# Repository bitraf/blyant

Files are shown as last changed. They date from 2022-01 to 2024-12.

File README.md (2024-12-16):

# Bitraf's musikalske blyant
Et elektronikk byggesett for å lære seg å lodde, som du også kan ha masse morro med. Settet er laget til [Bitraf's Crowdfunding kampanje i 2021](https://www.spleis.no/project/175973). Om du vil ha et sett nå etter kampanjen, kan du besøke Bitraf i Brenneriveien 9 og kjøpe ditt eget sett i Bitmart.

Byggesettet er basert på Drawdio og alle filene redistribueres her under samme lisens (CC BY-SA 3.0). Bitraf's version was made by [jenschr](https://github.com/jenschr). Based on work by Jay Silver in the Lifelong Kindergarten group at the MIT Media Lab (CC BY-SA 3.0). 

## Instruksjoner
For å bygge settet trenger du en loddebolt, en avbiter-tang og litt loddetinn. Om du ikke har dette kan du stikke innom Bitraf og låne utstyr hos oss. Følg [instruksjonene du finner her](instruksjoner/instruksjoner.md), så kommer du i mål.

### Innhold i settet
* Blyant
* Kobber-tape
* Tegnestift
* 2 strips/buntebånd
* Lilla kretskort
* Høyttaler
* 300k brun motstand (R2)
* 10k liten, oransje motstand (R1)
* 0.1uF oransje kondensator (C2)
* 680pF blå kondensator (C3)
* 100uF polarisert kondensator (C1)
* PN2222 transistor
* PN2907ATF transistor
* TLC551CP chip
* Chip-holder
* 2 Batteri-holdere

## skjematikk
Skjematikk for kretskortet finnes i form av [PDF](BitrafDrawdio_skjematikk.pdf) og komplette [Kicad-filer](kretskort/).

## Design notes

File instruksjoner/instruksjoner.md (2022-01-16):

# Instruksjoner
For å bygge settet trenger du en loddebolt, en avbiter-tang og litt loddetinn. Om du ikke har dette kan du stikke innom Bitraf og låne utstyr hos oss.

Komponentene faller lettere ut hvis du lodder de høye komponentene først. Det er derfor lurt å starte med de laveste komponentene. 

Start med de to motstandene (R1 og R2). Bøy bena ca 90 grader så de passer inn i hullene og skyv motstanden helt ned mot kortet så bena stikker langt ut på baksiden. Snu kortet og bøy litt bena ut.

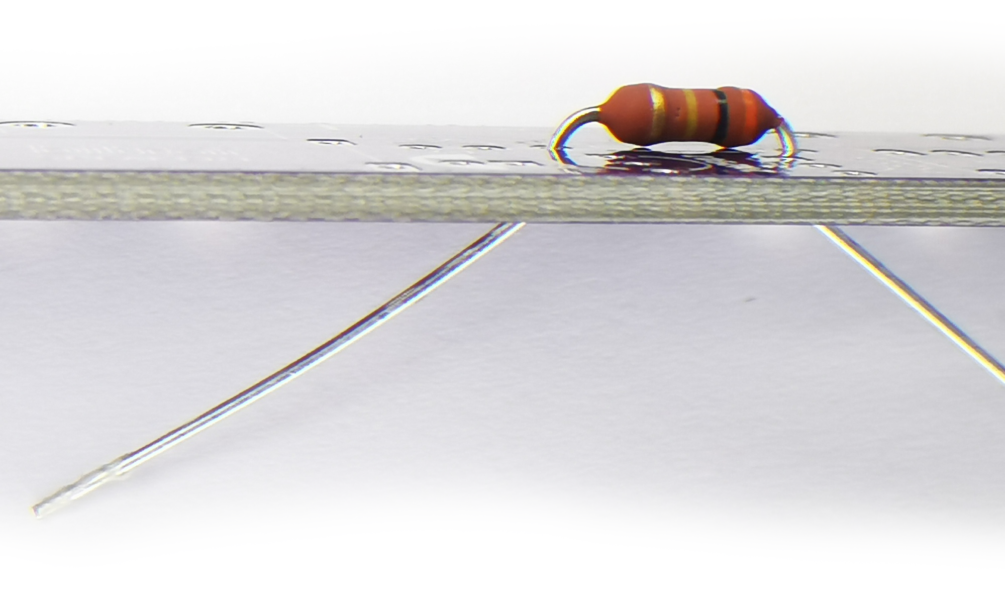
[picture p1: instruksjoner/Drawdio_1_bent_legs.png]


Dette gjør at motstanden holder seg på plass mens du lodder den. Det er lettere å få riktig mengde loddetinn hvis man bruker tynt loddetinn (0.5mm), men du kan bruke det du har tilgjengelig.

Start med å ta bittelitt loddetinn på tuppen av loddebolten - så lite at tuppen blir "våt", men ikke så mye at det danner seg en dråpe. Dette gjør det lett for varmen å krype fra loddebolten og over til det vi skal lodde. Plasser tuppen av loddebolten så den både rører hullet og benet på motstanden vi skal lodde.

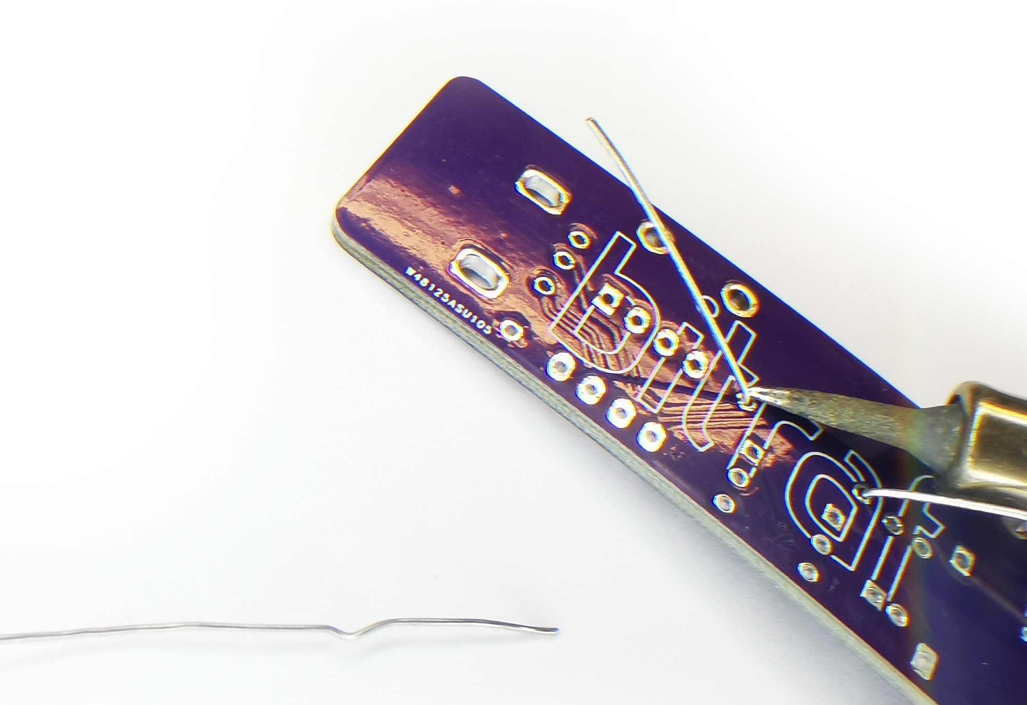
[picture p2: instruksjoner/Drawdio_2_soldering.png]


Målet er at du skal ta på nok loddetinn til å fylle igjen hullet, men ikke så mye at det ser ut som det ligger en dråpe der. Den perfekte mengden loddetinn ser ut som en liten fjelltopp som trekker seg oppover benet på komponenten. Hvis du ikke har så mye loddet før, anbefaler vi å sjekke ut den [flotte guiden](FullSolderComic_EN.pdf) som [Mighty Ohm](https://mightyohm.com/blog/2011/04/soldering-is-easy-comic-book/) har laget. Det er denne vi bruker på loddekurs på Bitraf.

Når begge bena er loddet, klipper du av bena så langt ned mot kortet som du kan med en tang.

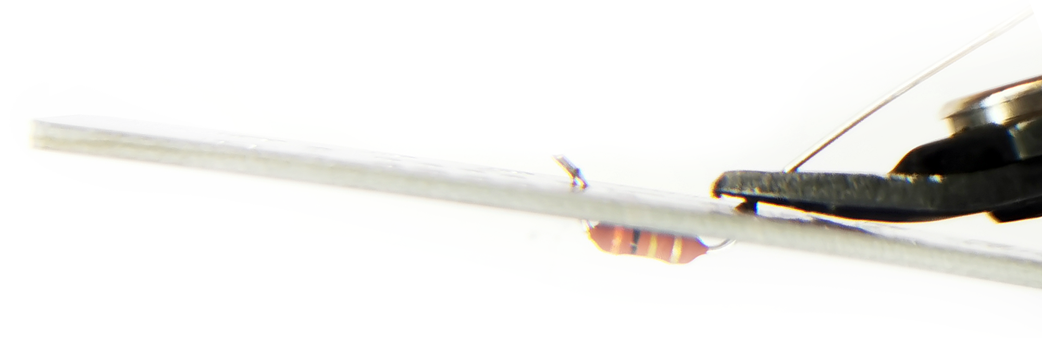
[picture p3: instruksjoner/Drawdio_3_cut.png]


Gjenta prosessen for den andre motstanden. Hvis du sliter med å finne noen av komponentene - let gjerne i nærheten av høyttaleren? Denne er magnetisk, så den har en viss samlende effekt... Vær også litt ekstra forsiktig med den, så ikke høyttaler-membranet blir skadet.

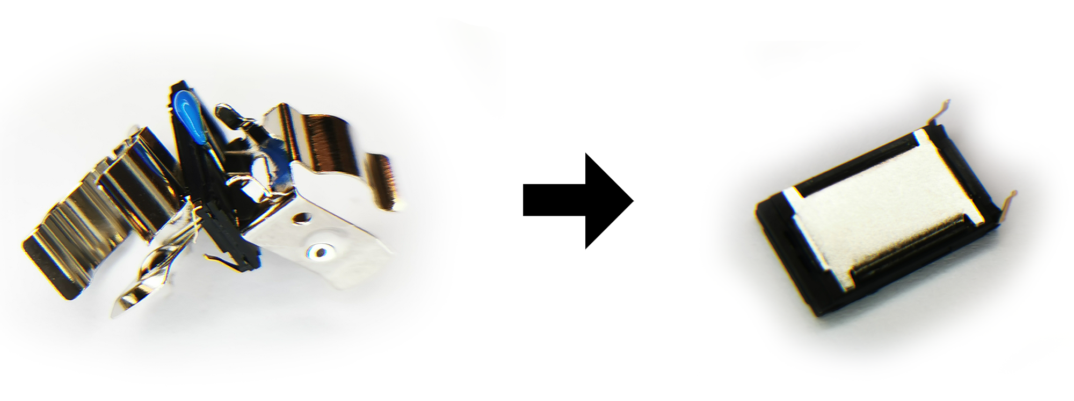
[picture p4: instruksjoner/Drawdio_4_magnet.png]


Lodd deretter de to kondensatorene som er små (C3 først og så C2). Når disse er på plass kan du ta frem høyttaleren. Bøy de to bena så de står rett opp når høyttaleren ligger med høyttaler-elementet ned mot bordet, slik som på bildet.

Når høyttaleren er loddet på plass, bør kretskortet ligne på bildet nedenfor.

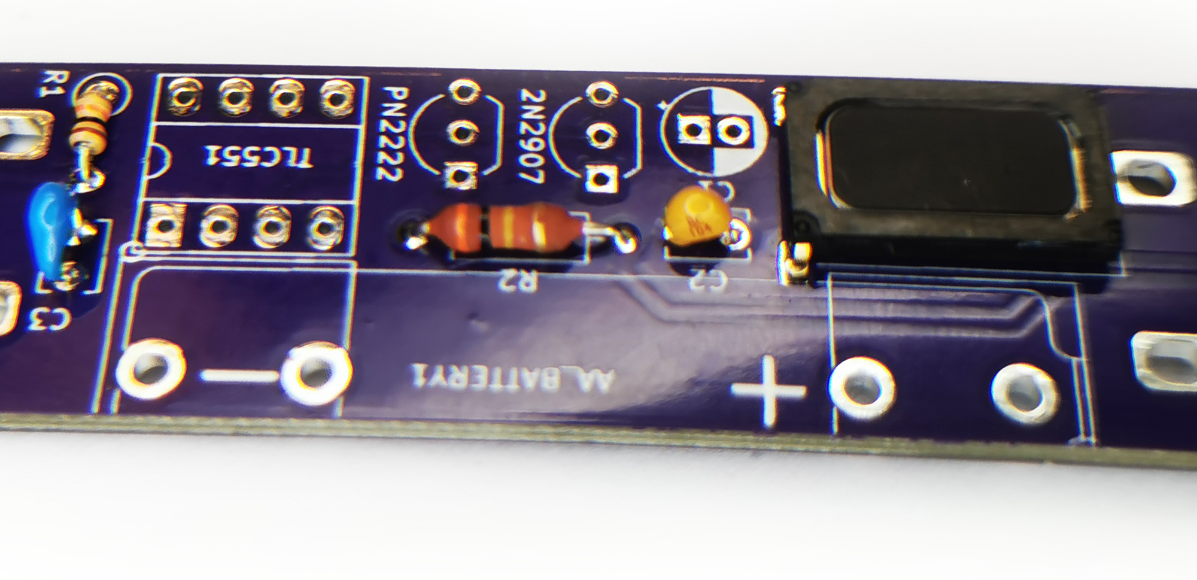
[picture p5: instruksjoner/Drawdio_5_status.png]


Den neste delen er holderen som sørger for at chippen ikke blir sittende feil vei. Denne har 8 ben og i den ene enden er det en liten bue. Denne er montert riktig vei når buen i plasten sitter samme vei som buen på kortet. Når du har satt denne på plass, kan du bøye et ben i hvert hjørne, slik at den holder seg på plass når du snur kortet rundt for å lodde.

Etter at alle 8 ben er loddet, kan du finne frem de to transistorene. Disse har 3 ben og det står skrevet noe med bitteliten skrift på den svarte plasten. Legg også merke til at der skriften står er det flatt, mens bakenfor er det buet. Dette skal stemme med bildet av flaten/buen som er trykt på kretskortet. Den første som skal monteres er transistoren som er merket med 2222A.

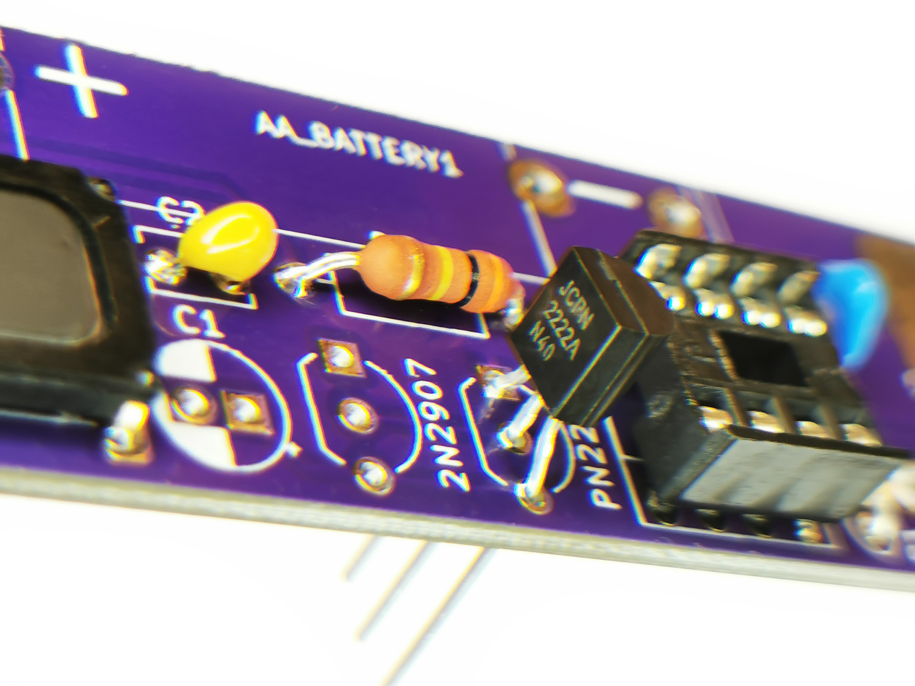
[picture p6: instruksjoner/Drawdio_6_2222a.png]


På den andre transistoren står det 2907a. Denne skal monteres rett foran den andre.

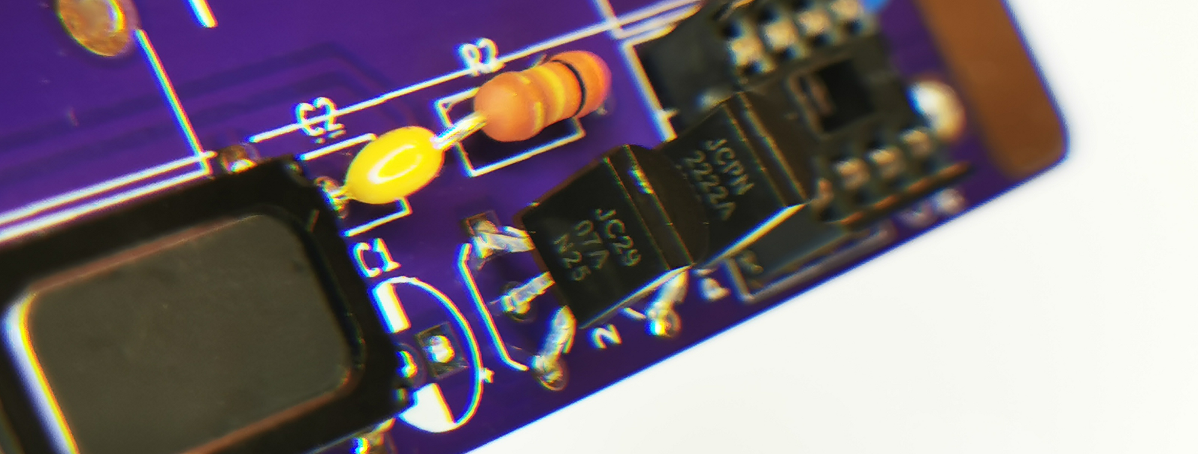
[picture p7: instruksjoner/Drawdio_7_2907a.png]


Den lille, runde "tønna" med to ben er også en kondensator, men denne må vi passe på å sette riktig vei. Ned langs siden på denne er det en lys stripe med minus-tegn på og denne skal peke mot høyttaleren.

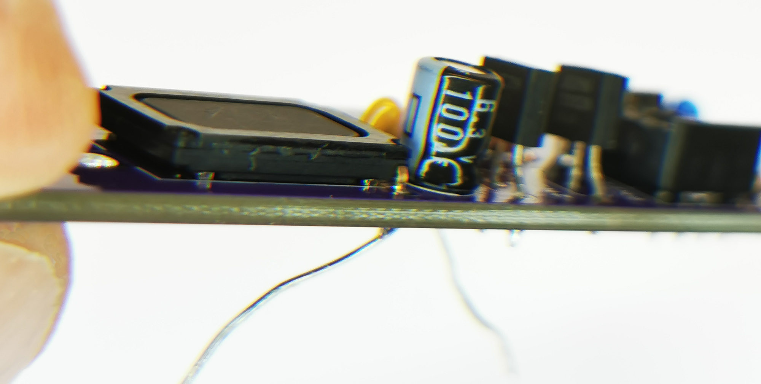
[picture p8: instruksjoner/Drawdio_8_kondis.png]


Bena på kondensatoren blir sittende ganske tett, så om det blir for mye loddetinn kan det danne seg en liten "lodde-bro". For å fjerne denne kan du bruke en loddepumpe (solder pump) eller loddeveke (solder braid) som du ser nedenfor. 

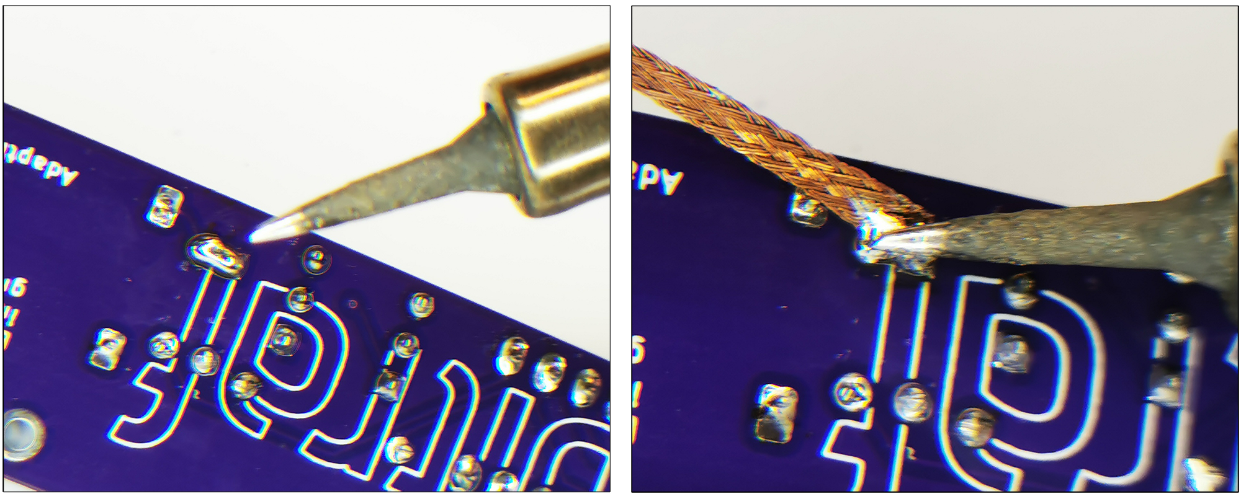
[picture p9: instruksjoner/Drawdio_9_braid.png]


Loddeveken suger til seg overfødig loddetinn når du varmer den opp. Noen ganger går det faktisk enda lettere hvis man tar på bittelitt loddetinn på veken. Dette er på samme måte som at en våt klut fjerner vann lettere enn en tørr klut.

Nå kan vi putte chippen forsiktig inn i holderen sin. Hold gjerne den ene siden med ben ned mot bordet mens du trykker forsiktig ned. På denne måten blir alle bena trykket like mye inn.

På toppen av chippen er det en liten prikk. Denne forteller oss hvor pinne 1 er og denne skal peke vekk fra høyttaleren slik som på bildet. Sjekk at din ligner på bildet

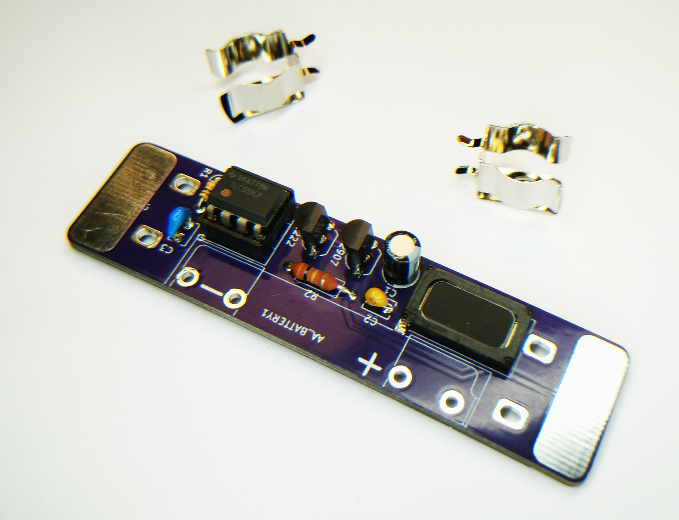
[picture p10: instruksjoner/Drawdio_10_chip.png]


Det neste er batteri-holderen. Dytt pinnene ned i hullene og lodd fra baksiden som for alt det andre. Disse hullene er store, så du trenger mye loddetinn for å fylle dem opp. Om du sliter med å få loddetinnet til å smelte i hullet - ta loddetinn på loddebolten så går det lettere.

Når batteri-holderne er montert kan du teste om elektronikken virker! Putt inn batteriet og ta på endene av elektronikken så skal det komme lyd! Det blir litt lavere lyd når strømmen skal gjennom blyanten, men det er lurt å teste før man går videre. Hvis det ikke kommer lyd, gå tilbake i instruksjonene og sjekk at du har fått med deg alt. Pass spesielt på orienteringen av den runde kondensatoren.

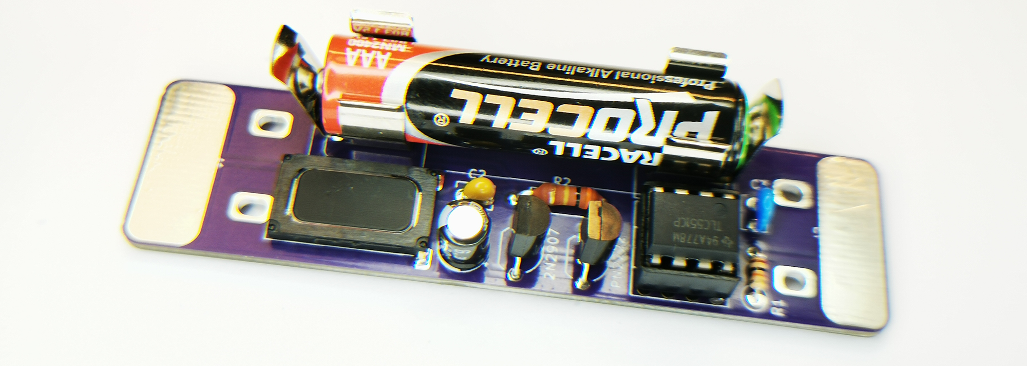
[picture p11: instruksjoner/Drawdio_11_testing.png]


Da er det tid for montere blyanten. Finn frem strips, kobber-tape, tegnestift og blyant. Tre stripsene inn i hullene i kretskortene. Pass på at de er rotert riktig vei.

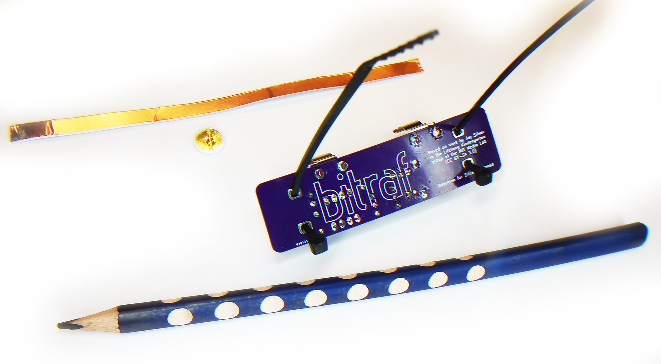
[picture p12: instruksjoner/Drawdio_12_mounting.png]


Lukk stripsene, men ikke før du har puttet inn blyenten. Kretskortet skal sitte helt øverst på blyanten og kretskortet skal roteres så høyttaleren er ved enden av blyanten. Stram stripsene rundt blyanten så godt du klarer. Når du er ferdig, kan du klippe av det som stikker ut på strips'en. 

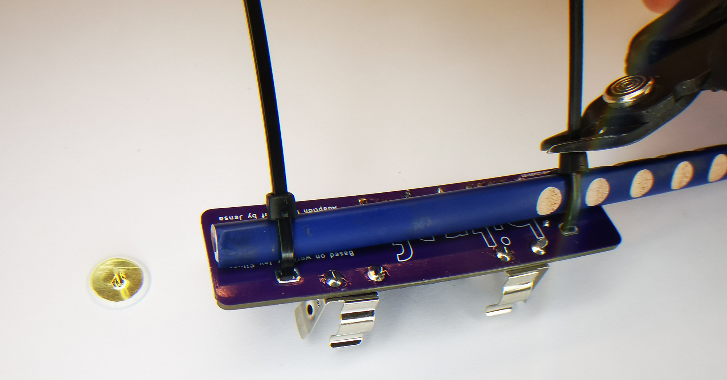
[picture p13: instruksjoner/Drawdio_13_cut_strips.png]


Riv av en bitteliten bit av kobber-tapen som er lang nok til å gå fra kretskortet og til enden av blyanten. Stikk tegnestiften gjennom tapen så den treffer blyet i midten av blyanten. Det er dette som lager koblingen fra elektronikken og ned på papiret.

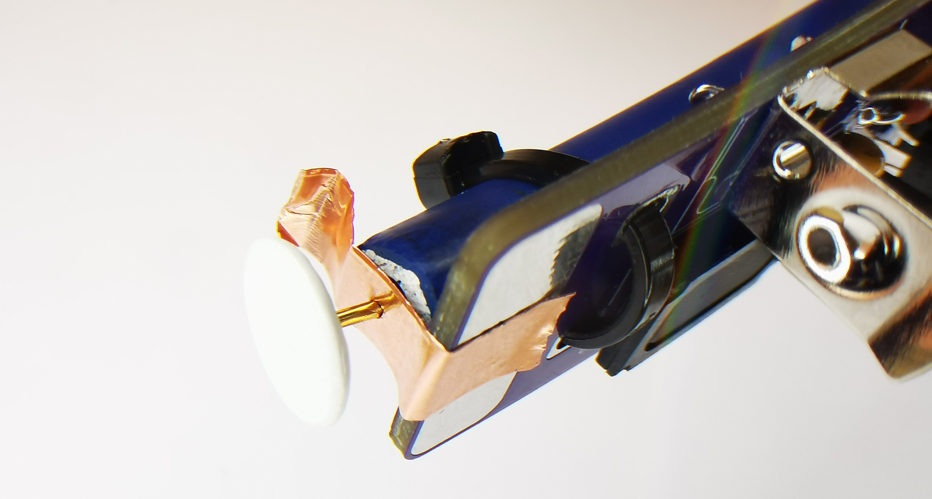
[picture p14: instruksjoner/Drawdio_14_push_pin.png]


Den resterende tapen skal festes nedover blyanten - for eksempel som på bildet nedenfor.

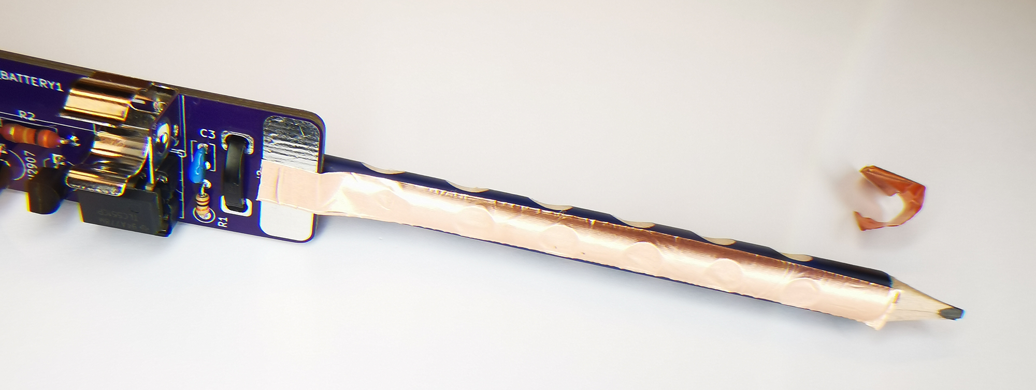
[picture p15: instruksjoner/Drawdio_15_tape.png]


Nå er alt klart til bruk! Start med å tegne en tykk strek (med mange streker frem og tilbake). Tegn med den ene hånden og hold fingeren på den andre hånden et annet sted på streken så kan du høre at du tegner! Vis frem til venner og familie!

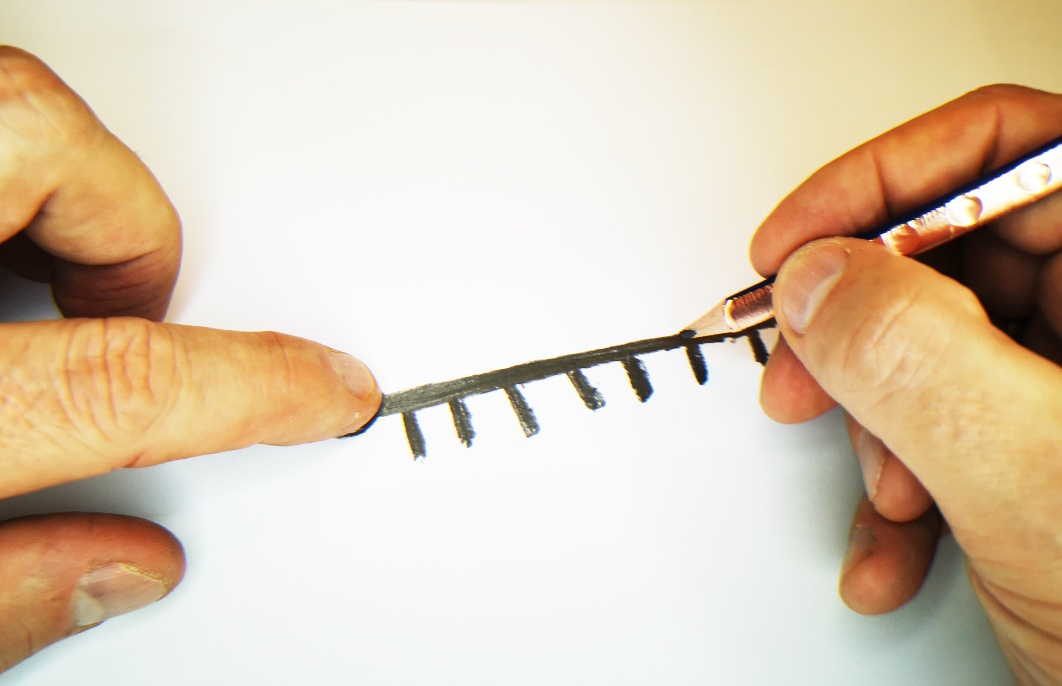
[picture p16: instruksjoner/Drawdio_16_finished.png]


Med litt øvelse kan du tegne små instrumenter som kan spilles på! Husk å ta batteriet ut av blyanten når du ikke bruker den, ellers vil batteriet lades ut ganske raskt.

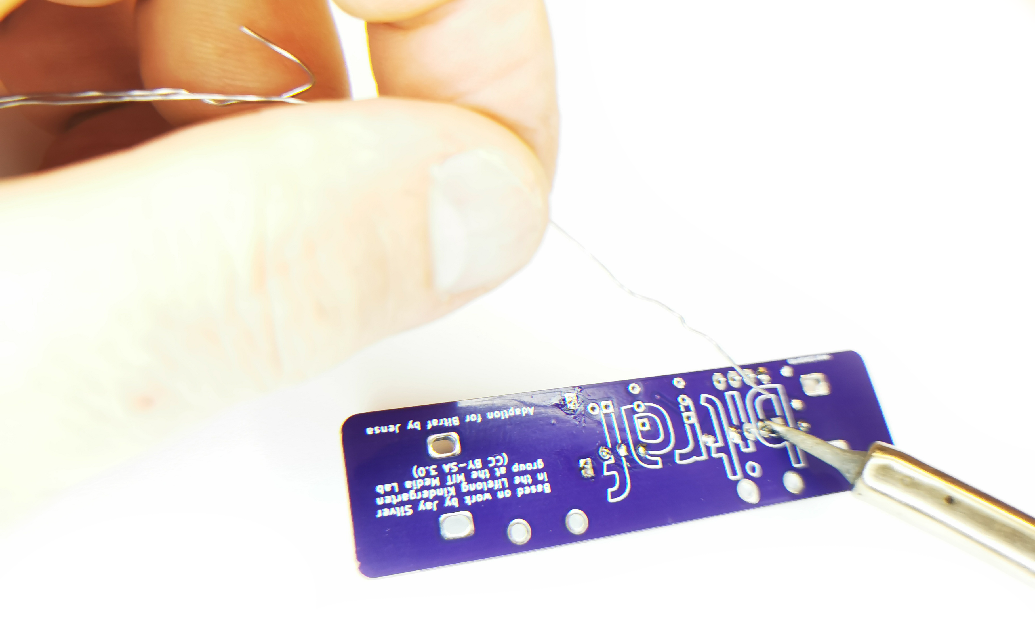
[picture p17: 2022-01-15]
instruksjoner/Drawdio_5_holder.png

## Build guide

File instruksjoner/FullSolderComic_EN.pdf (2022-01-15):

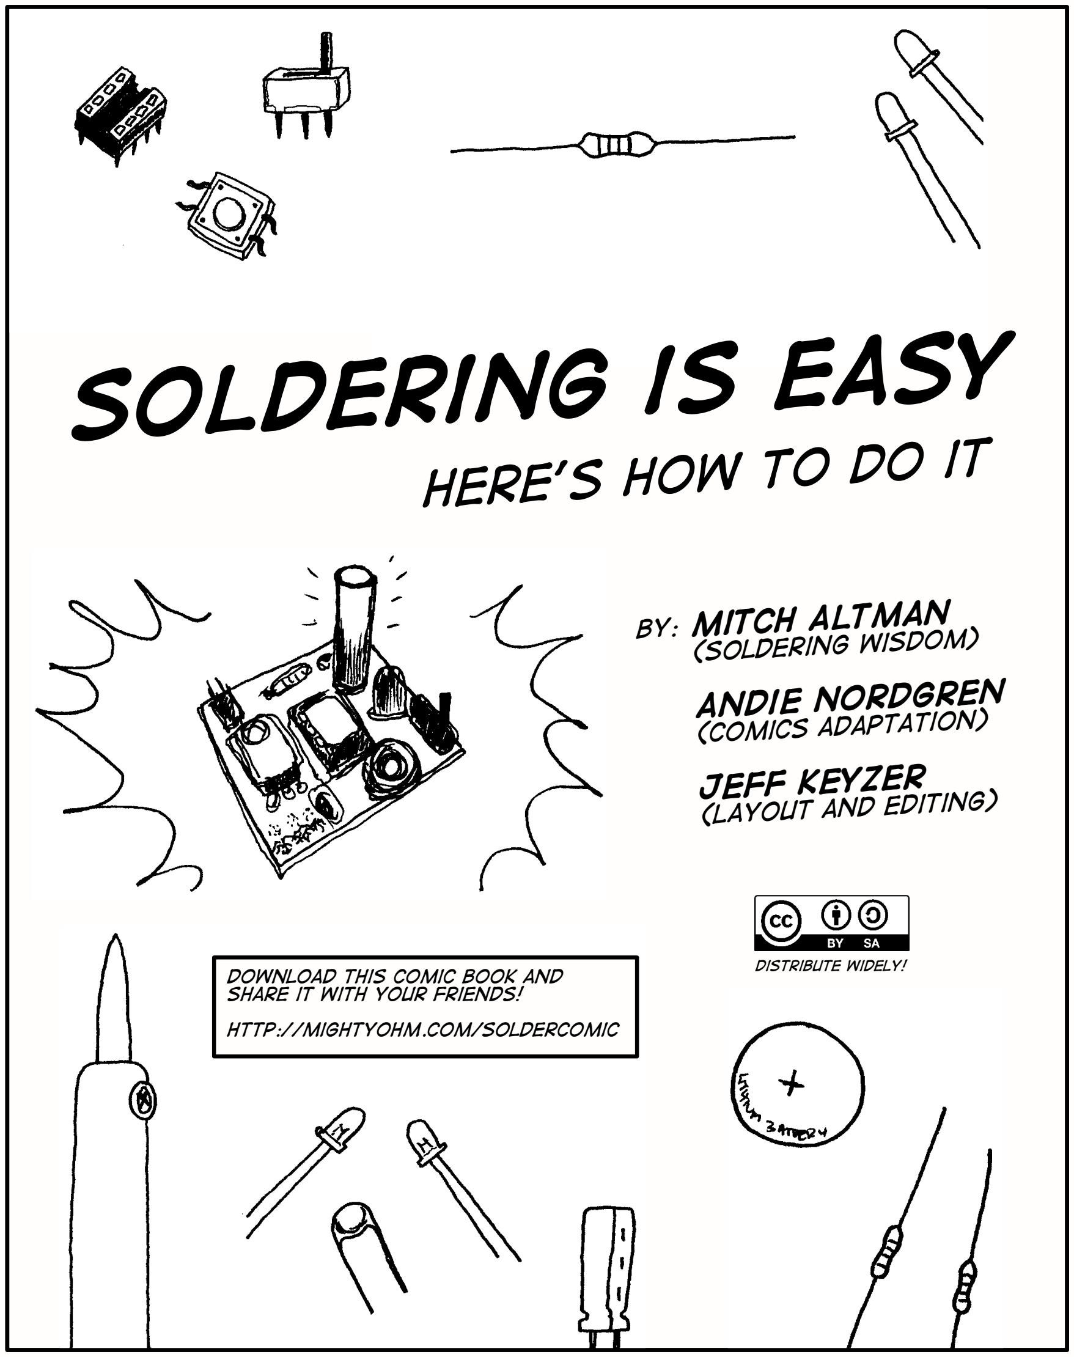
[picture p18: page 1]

# Soldering is easy

# here's how to do it

# by: Mitch Altman

# (soldering wisdom)

# Andie Nordgren

# (Comics adaptation)

# Jeff Keyzer

# (Layout and editing)

## Distribute widely! Download this comic book and share it with your friends!

## http://mightyohm.com/soldercomic

Soldering is a really useful skill.

# It is also way easy!

### REally, it is!

You’ll see.

### Soldering is also lots of fun!

If you know how to solder, you can make just

## about anything with electronics, which is

just too cool!
There are many ways to make good solder connections.
I’m going to explain how I do it.

# Let's get started!

This is a soldering iron.

Its tip gets hot enough to melt solder, which is metal.
That's about 200 degrees Celsius!

### Safety tip #1 (of 3): If you touch the tip, you will

### let go very quickly!

This is solder.
It is made of metal, Usually tin and lead.

the elements

### Sn and Pb

## It is actually hollow and filled with rosin

(similar to the stuff used to make bows for violins

sticky).

### When the solder heats up, the rosin melts almost immediately

The Metal
follows
shortly
thereafter

The ROSIN flows around what you want to solder, cleans the metal, and helps make a good solder connection.

We use the soldering iron to melt the solder and make electrical connections.

### The best solder for electronics has

rosin core and is 60% tin, 40% lead.
also known
as flux

There are other types, for instance lead-free solder, but it has toxic chemicals in its core, and it is not quite as easy to use as solder with lead. It also corrodes soldering iron tips quickly. If you can only get lead-free solder where you live, it’s OK, but please don’t breathe in the nasty smoke.

# Safety tip #2 (of 3):

## Lead is poisonous. It gets

on your skin when you hold the

## solder, so wash your hands after soldering!

If you don’t wash your hands after soldering, the lead may get in your body, where it gets stored in your brain for your entire life. if enough collects there then you go insane, and you lose all of your friends. So - wash your hands after soldering, and keep your friends!

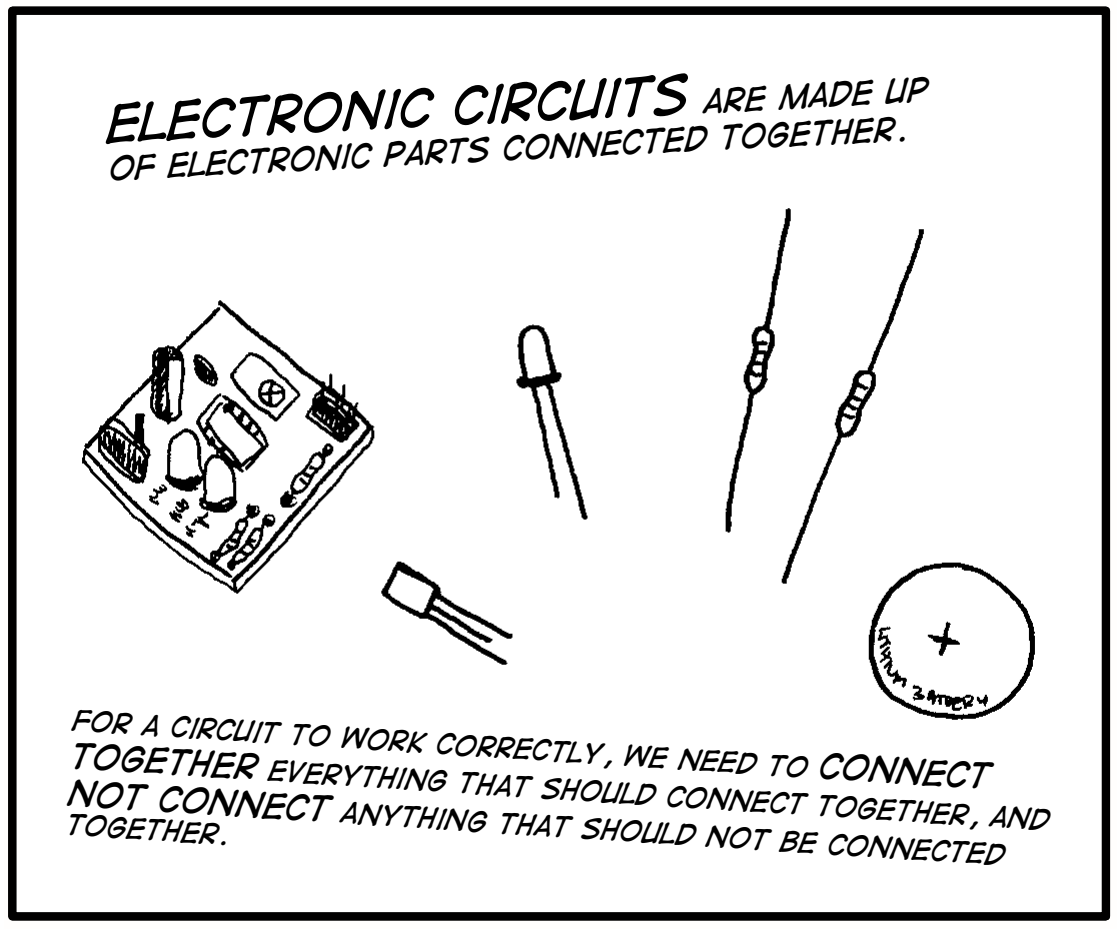
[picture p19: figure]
Electronic circuits are made up of electronic parts connected together.; connect; together.

For a circuit to work correctly, we need to
together everything that should connect together, and not connect anything that should not be connected

There are many ways to connect electronic parts together, but perhaps the easiest way is with a

# Printed Circuit Board

PCB or
just

### "THE

### Board"

The PCB makes
it easy because
it has

# pads for

each part.

If you look carefully at the PCB, you will see lines connecting pads together with other pads – these lines are called traces.

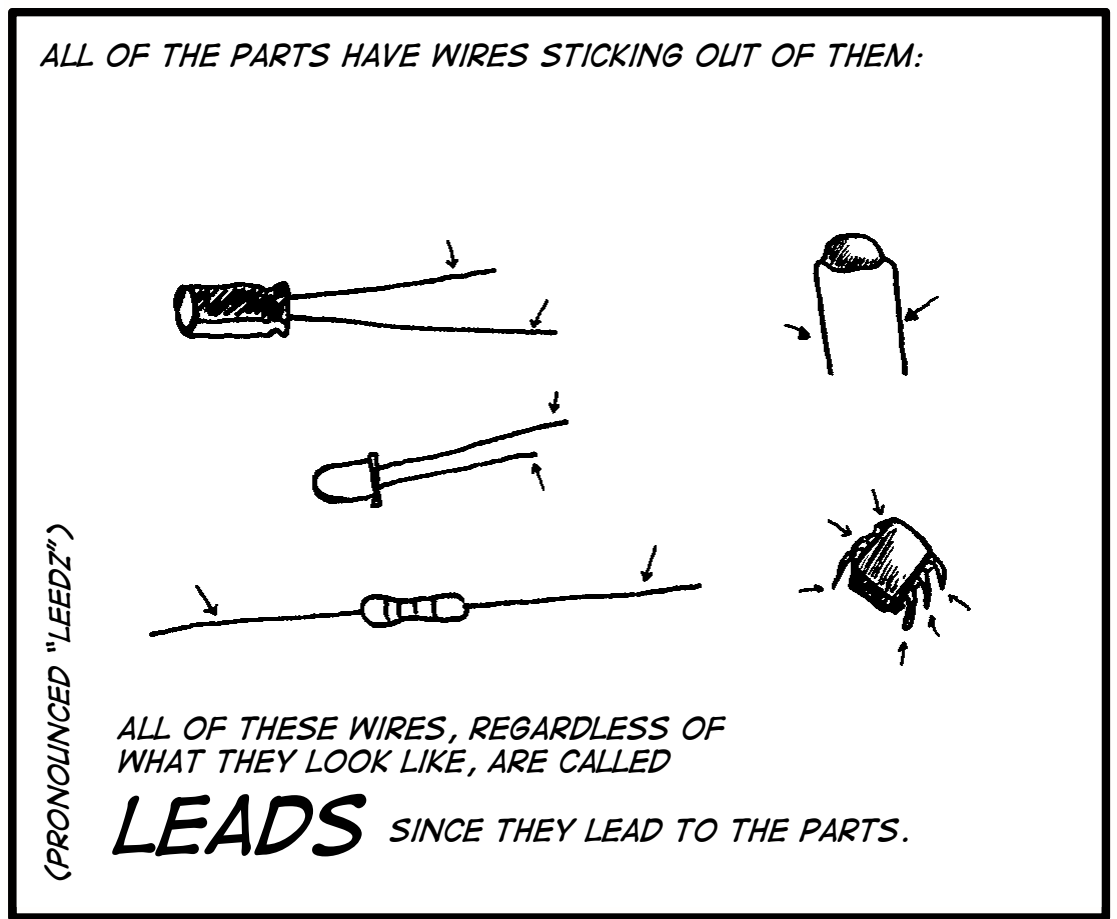
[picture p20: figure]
leads; (pronounced “leedz”); All of these wires, regardless of what they look like, are called; since they lead to the parts.

All of the parts have wires sticking out of them:

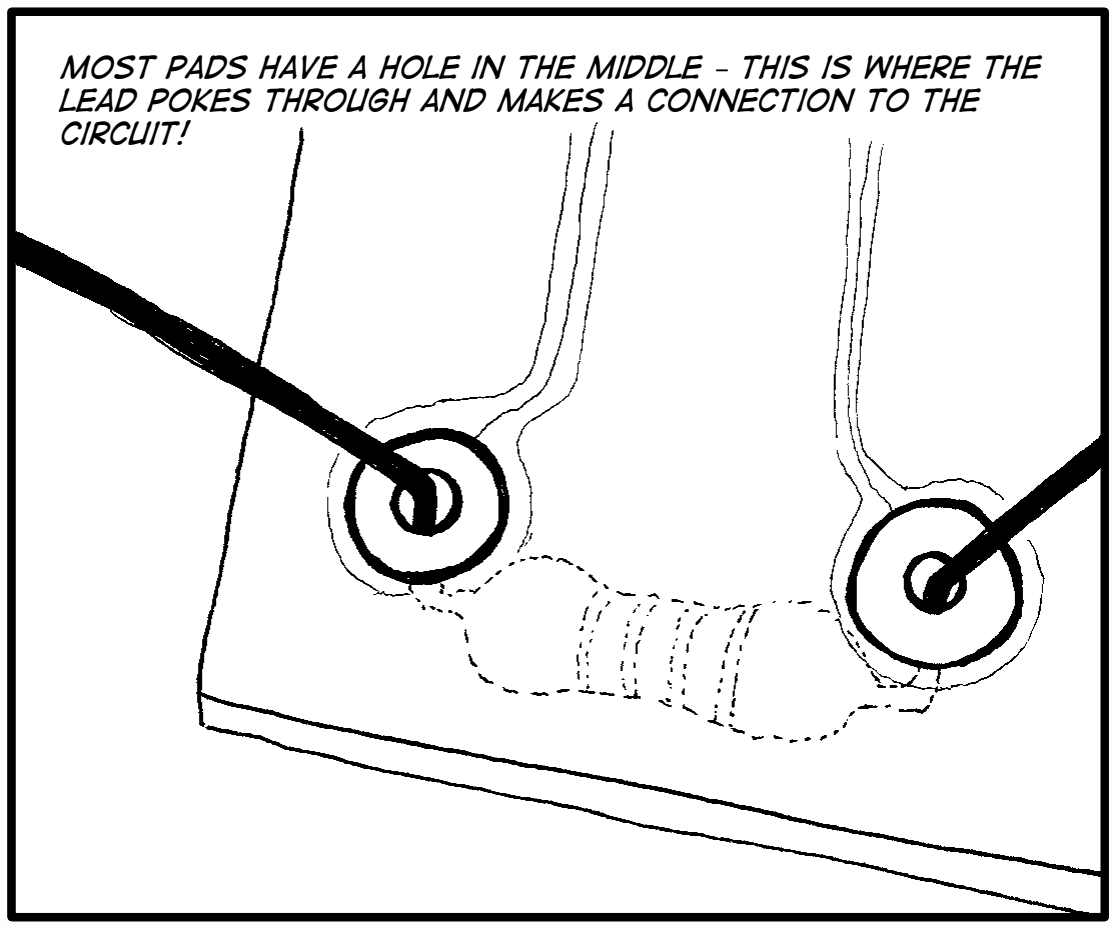
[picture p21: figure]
circuit!

Most pads have a hole in the middle – this is where the lead pokes through and makes a connection to the

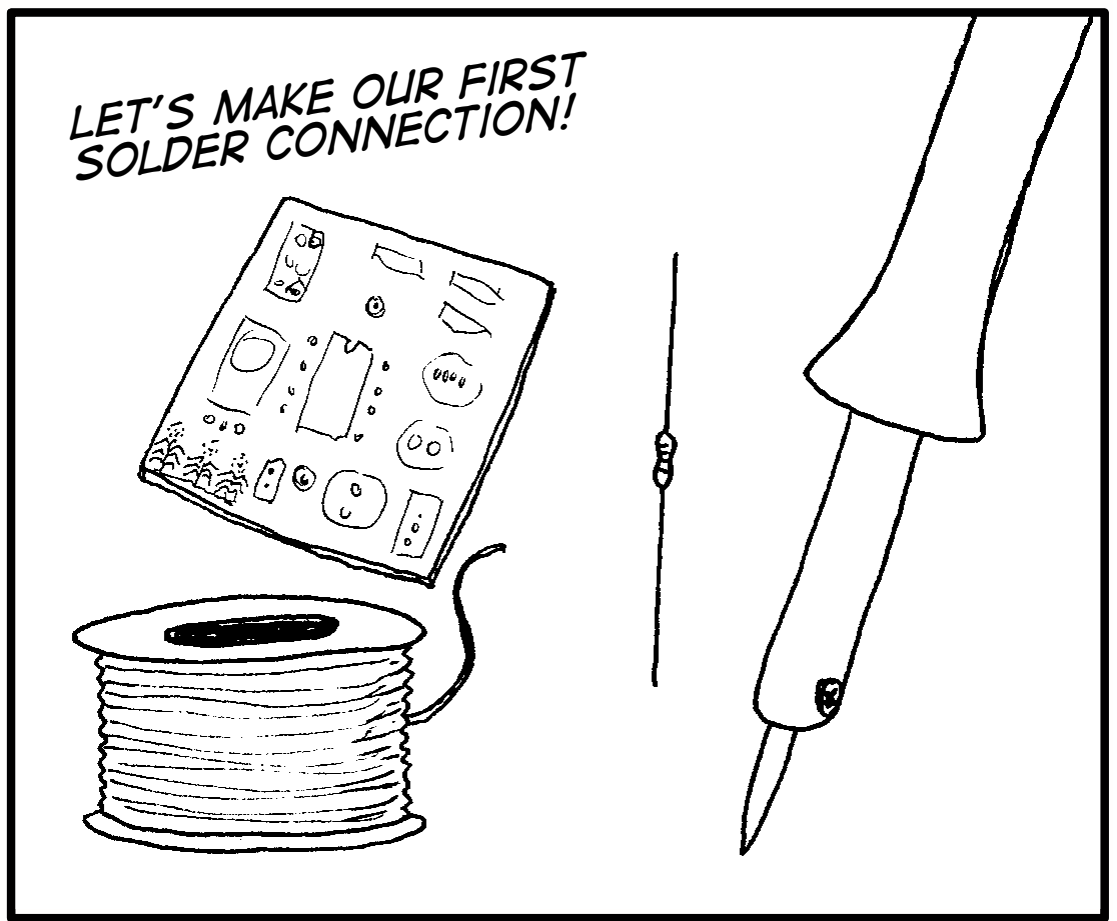
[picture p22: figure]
Let’s make our first solder connection!

If you put all of the leads from the parts into

### the correct pads for the parts

and if you put all of the parts in the correct

### orientation and if you make all good solder connections

# then the circuit will just work!

This is because the board connects everything that should be connected, and nothing that should not be connected.

some parts
can go in the
wrong way!

We’ll start with a resistor.

Resistors have two leads and (unlike some parts, such as diodes, which have a “plus” side and a “minus” side) can be placed in their pads in either direction.

PCBs usually have markings to show where each part goes (and if the orientation matters, the PCB usually has some way to show you this).

Since the word “resistor” starts with the letter “R”, the PCB usually marks places where resistors go with an “R”, followed by the resistor’s number, such as “R3”

So, to solder in the resistor, you start by finding the correct value of resistance from the project’s documentation.

Then bend the two
leads of the resistor
down the width of the
part, like this:

Then place the two
leads through the two
pads on the PCB for
this resistor.

For most PCBs, all of the parts are placed through the pads on the printed side of the PCB (which we’ll call the top of the board), and we’ll solder all of the pads on the bottom of the board.

You push the resistor’s
leads through the pads
until the part rests flat
on the PCB

(sometimes you may need to wiggle and tug gently on the leads from the bottom of the PCB to do this).

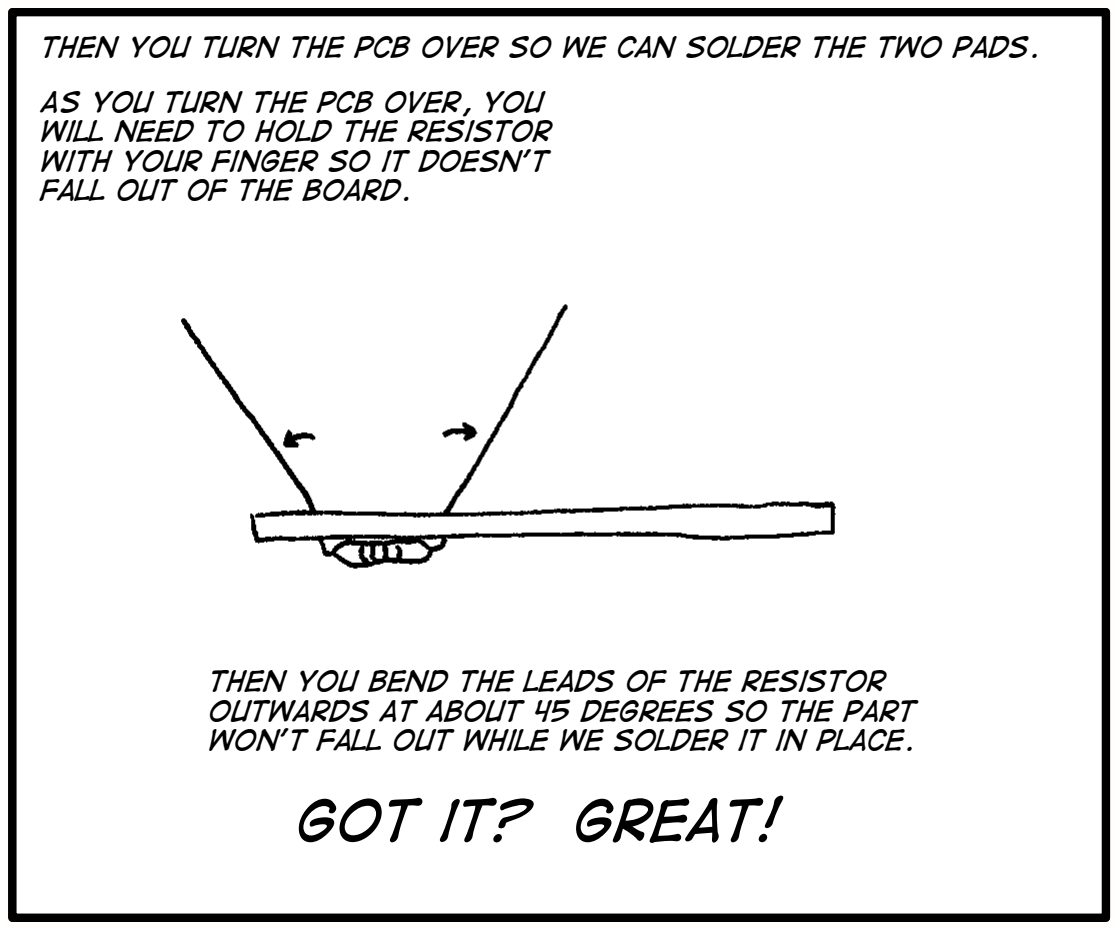
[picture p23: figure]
As you turn the PCB over, you will need to hold the resistor with your finger so it doesn’t fall out of the board.; then you bend the leads of the resistor; Got it? Great!
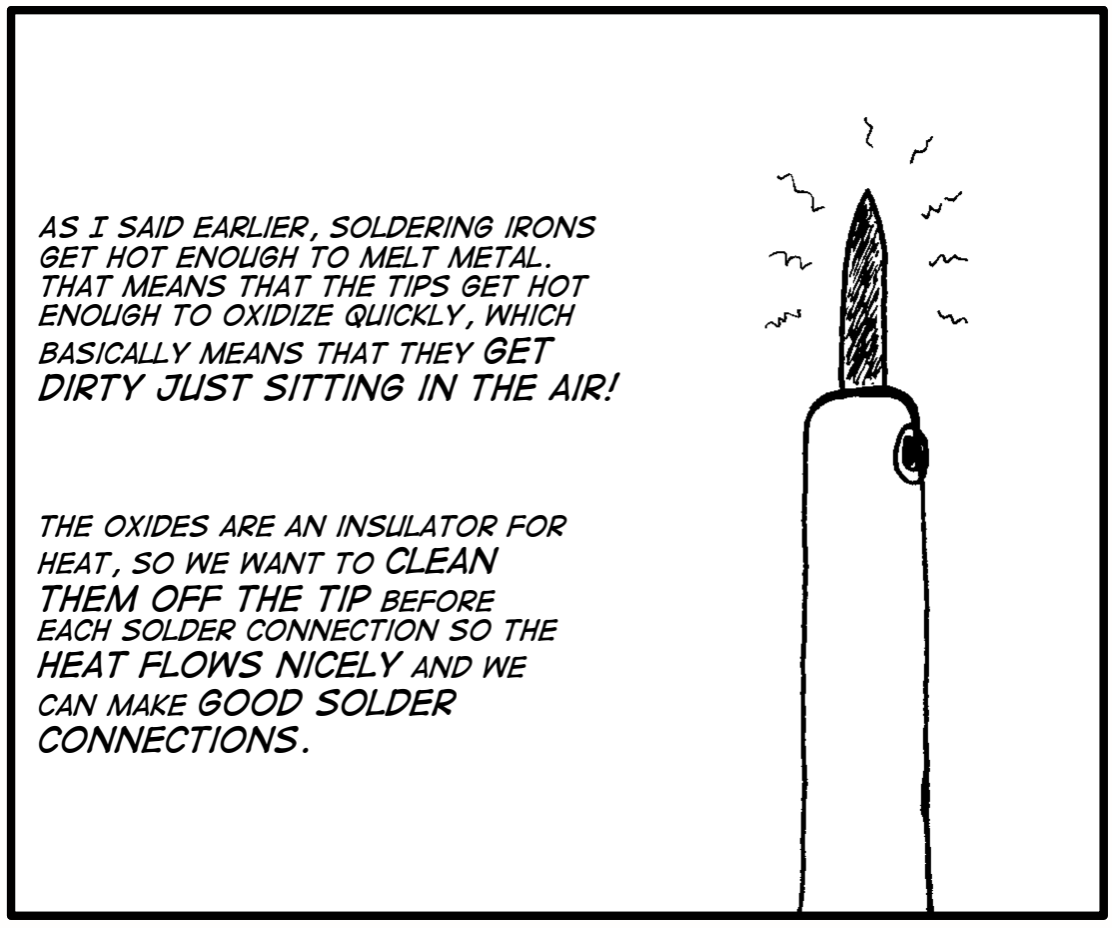
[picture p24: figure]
As I said earlier, soldering irons get hot enough to melt metal. That means that the tips get hot enough to oxidize quickly, which basically means that they get dirty just sitting in the air!; The oxides are an insulator for heat, so we want to clean them off the tip before each solder connection so the heat flows nicely and we can make good solder connections.

Then you turn the PCB over so we can solder the two pads.

outwards at about 45 degrees so the part won’t fall out while we solder it in place.

This is why we have a wet sponge:
to clean the oxides off the tip. Just scrape the
tip across the sponge gently,

### then rotate the iron and scrape gently

across the sponge again.

This should make the tip silvery and somewhat shiny – ready

### to solder. Remember to clean the tip like this before each connection you make – the tips oxidize

quickly!

### If the tip is nice and silvery and shiny, you

can make good connections.

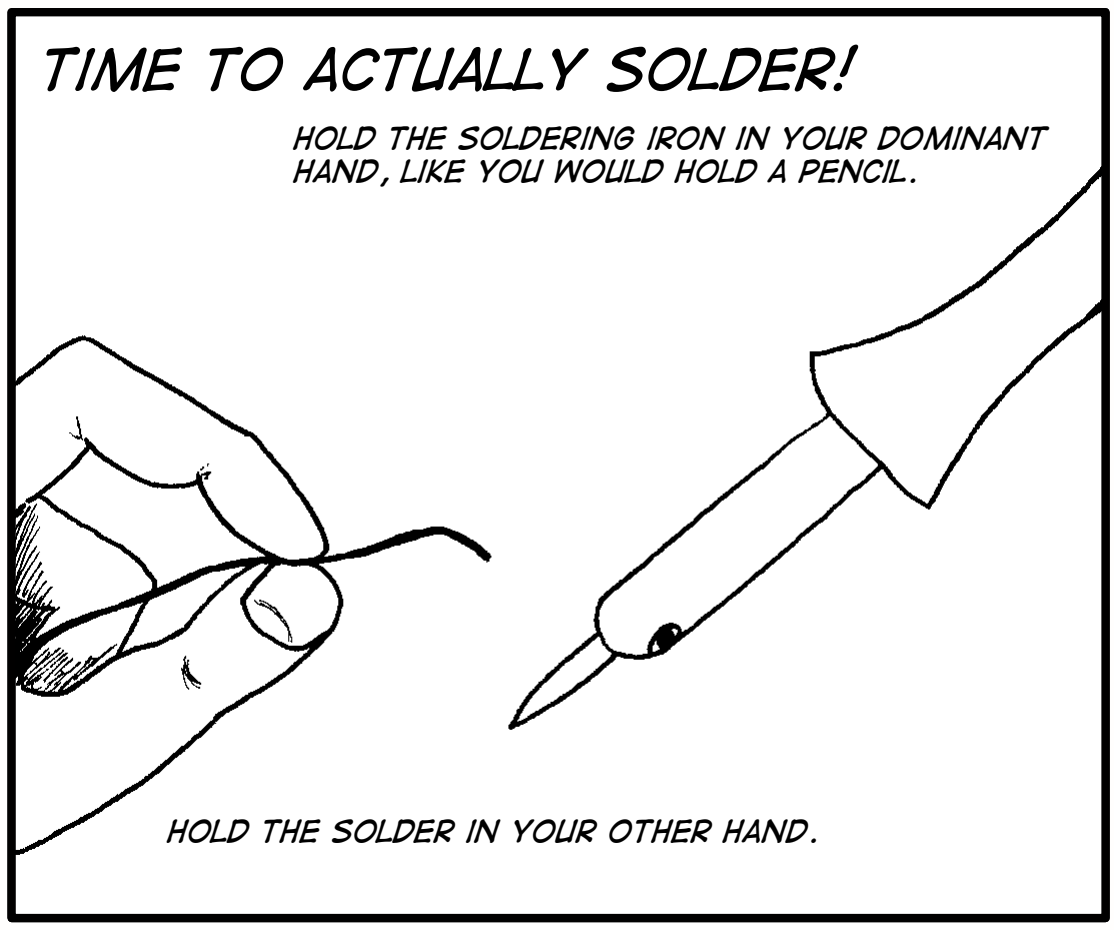
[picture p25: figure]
Time to actually solder!; hand, like you would hold a pencil.; Hold the solder in your other hand.

Hold the soldering iron in your dominant

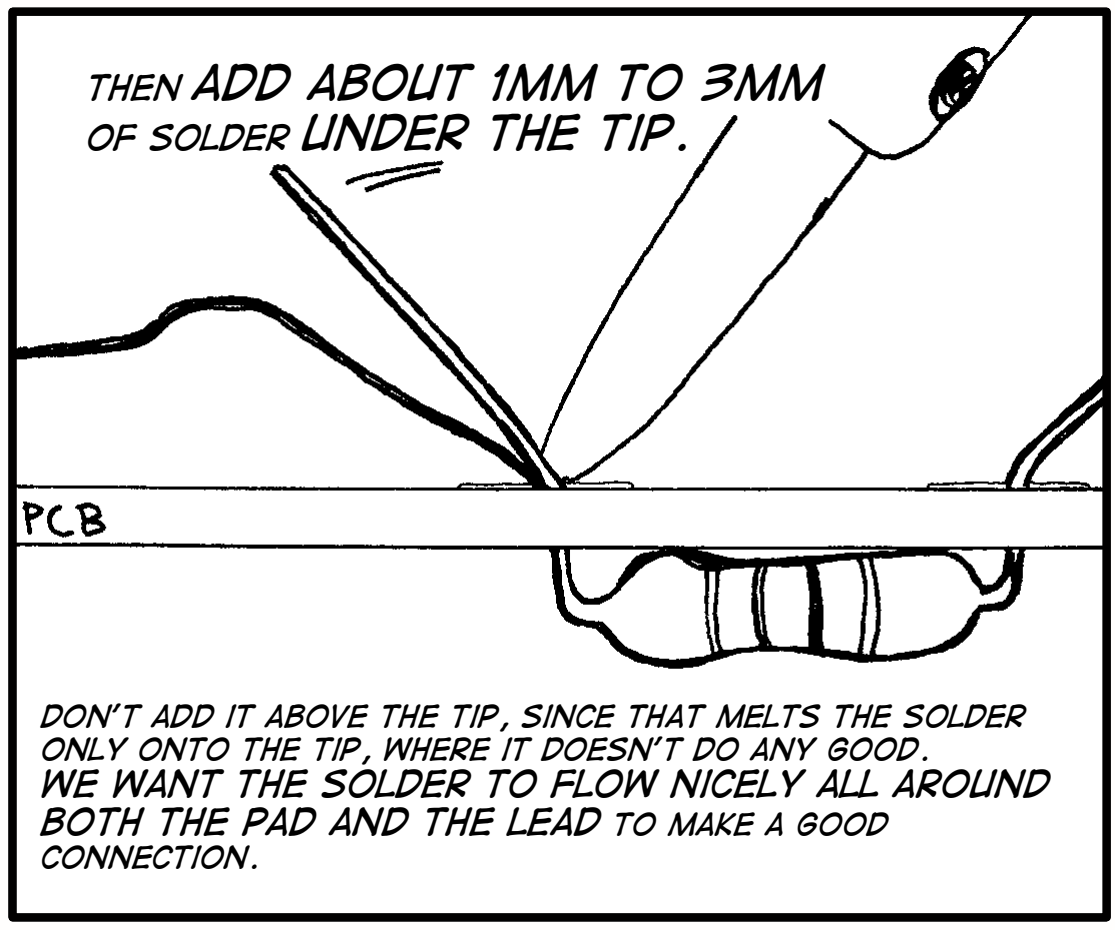
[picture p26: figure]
Then add about 1mm to 3mm of solder under the tip.; connection.

Don’t add it above the tip, since that melts the solder only onto the tip, where it doesn’t do any good.

### we want the solder to flow nicely all around both the pad and the lead to make a good

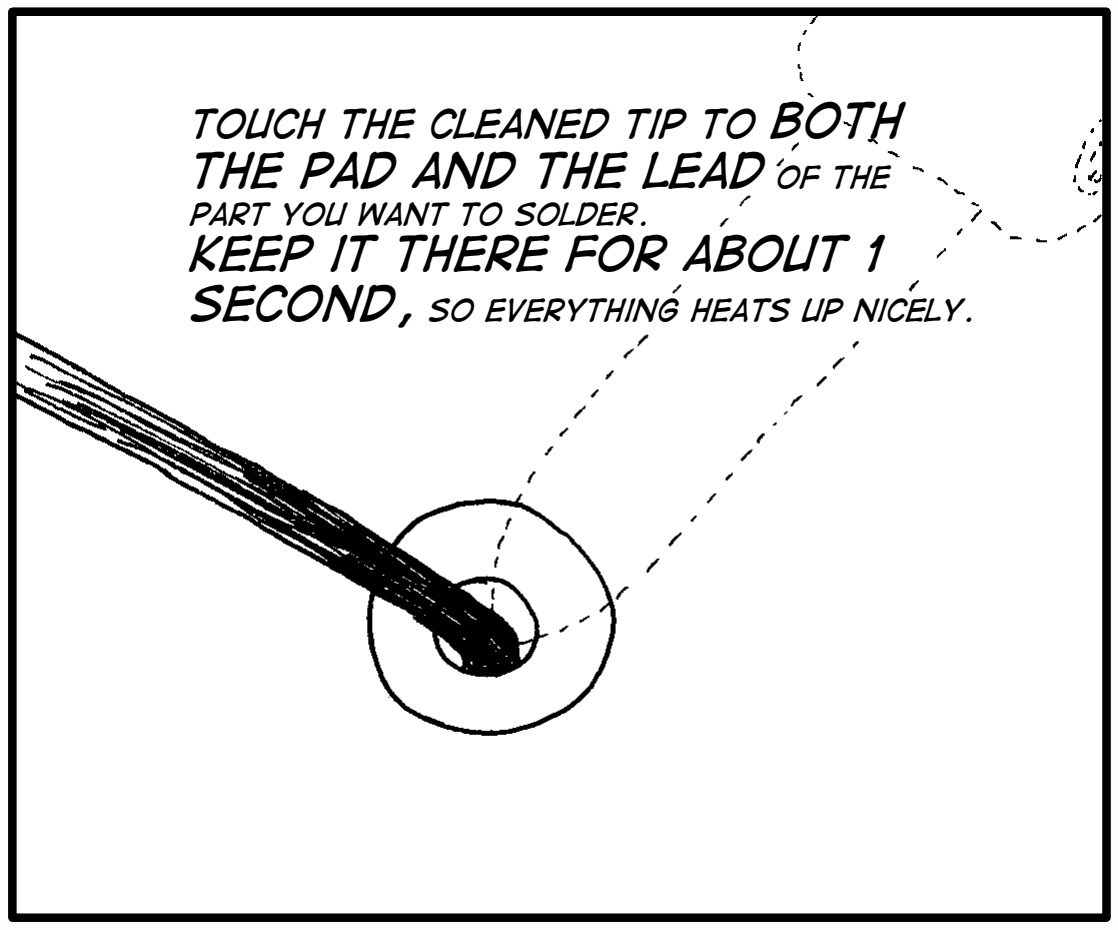
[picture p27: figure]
Touch the cleaned tip to both the pad and the lead of the; part you want to solder. Keep it there for about 1; second, so everything heats up nicely.
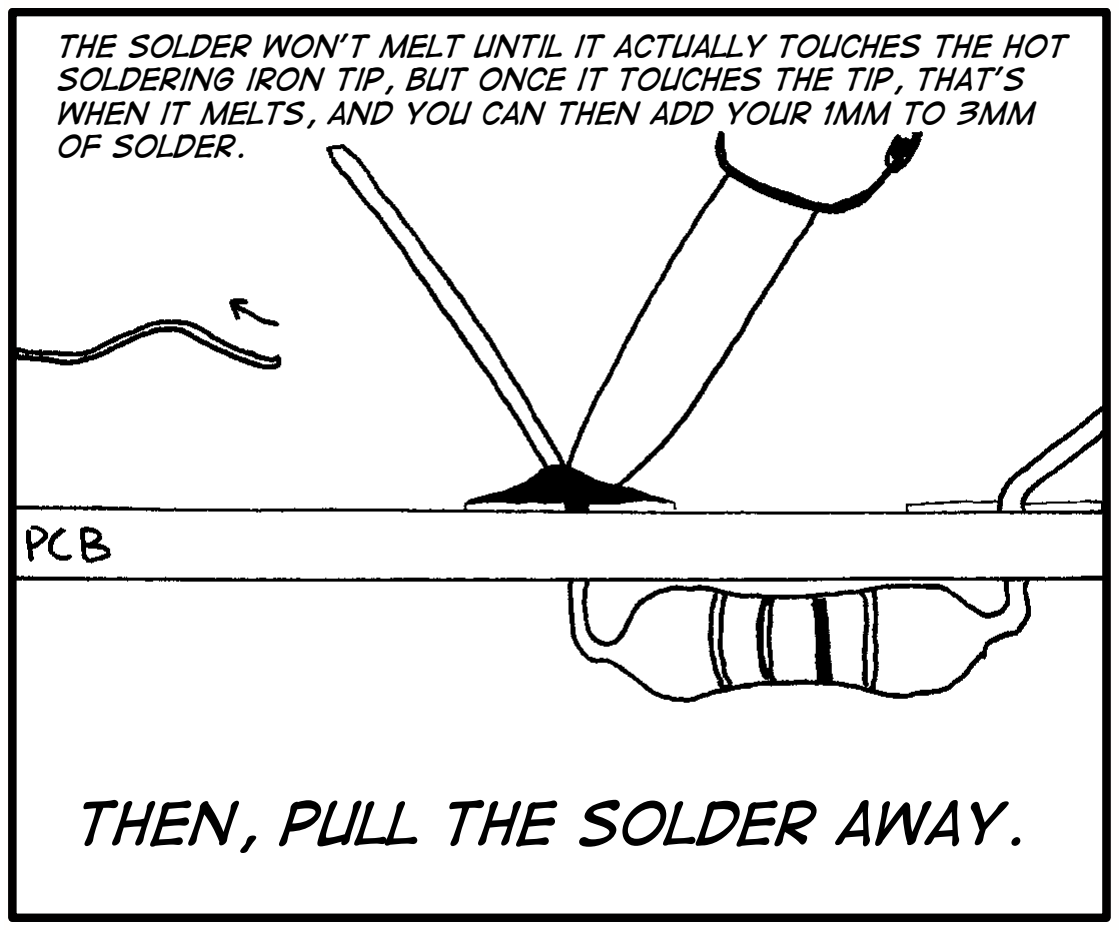
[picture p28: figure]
of solder.; Then, pull the solder away.

The solder won’t melt until it actually touches the hot soldering iron tip, but once it touches the tip, that’s when it melts, and you can then add your 1mm to 3mm

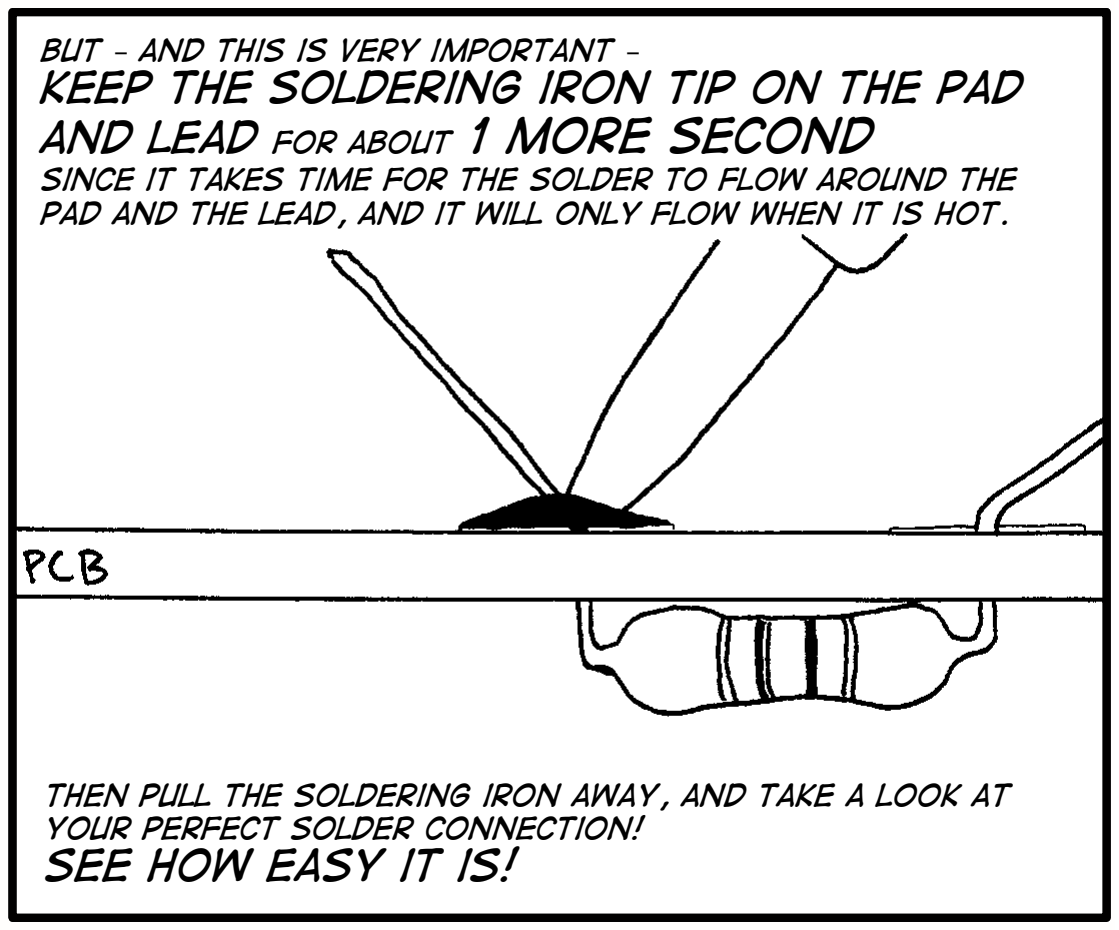
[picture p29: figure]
But – and this is VERY important – keep the soldering iron tip on the pad and lead for about 1 more second; your perfect solder connection! See how easy it is!

since it takes time for the solder to flow around the pad and the lead, and it will only flow when it is hot.

Then pull the soldering iron away, and take a look at

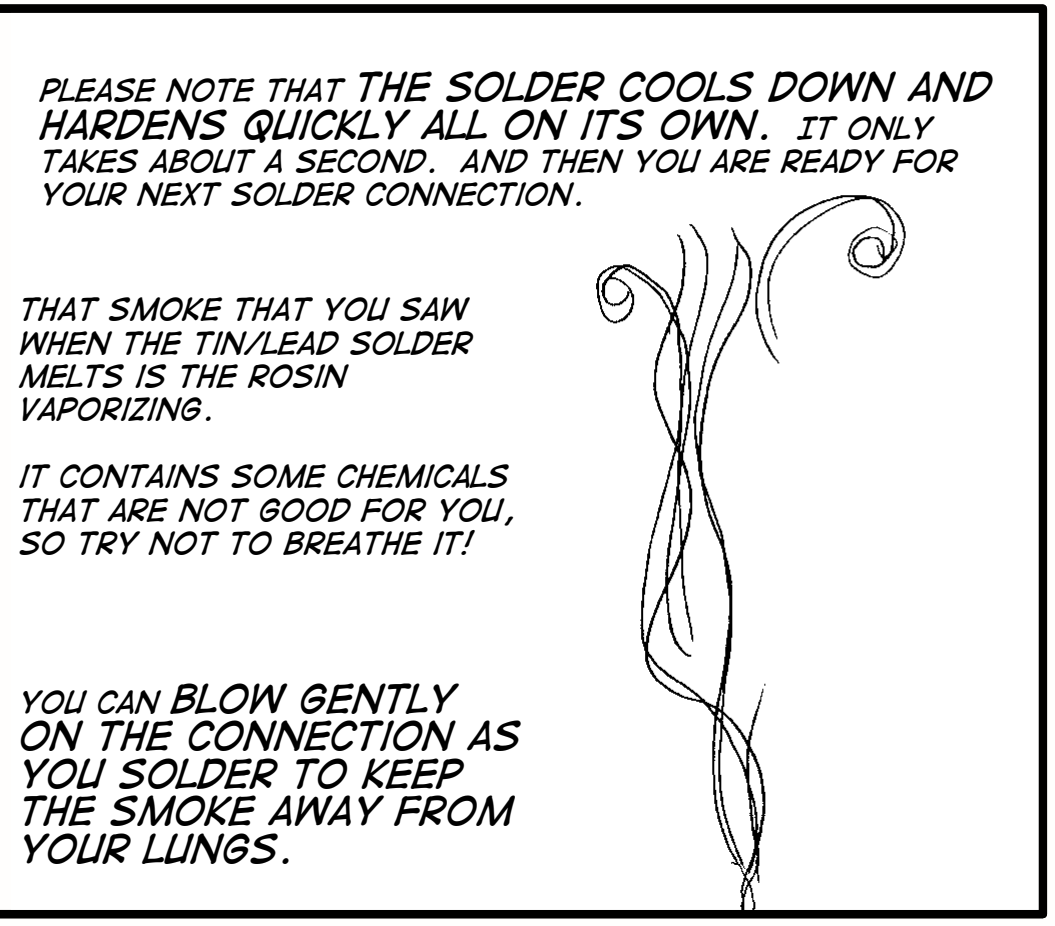
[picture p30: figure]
hardens quickly all on its own. It only; your next solder connection.; That smoke that you saw when the tin/lead solder melts is the rosin vaporizing.; it contains some chemicals that are not good for you, so try not to breathe it!; you can blow gently on the connection as you solder to keep the smoke away from your lungs.

## Please note that the solder cools down and

takes about a second. And then you are ready for

### Now put that soldering iron back in its stand

while we’re not using it.

## The stand keeps the hot iron safely on the

table. Most people say that it’s not fun to have it land in your lap!

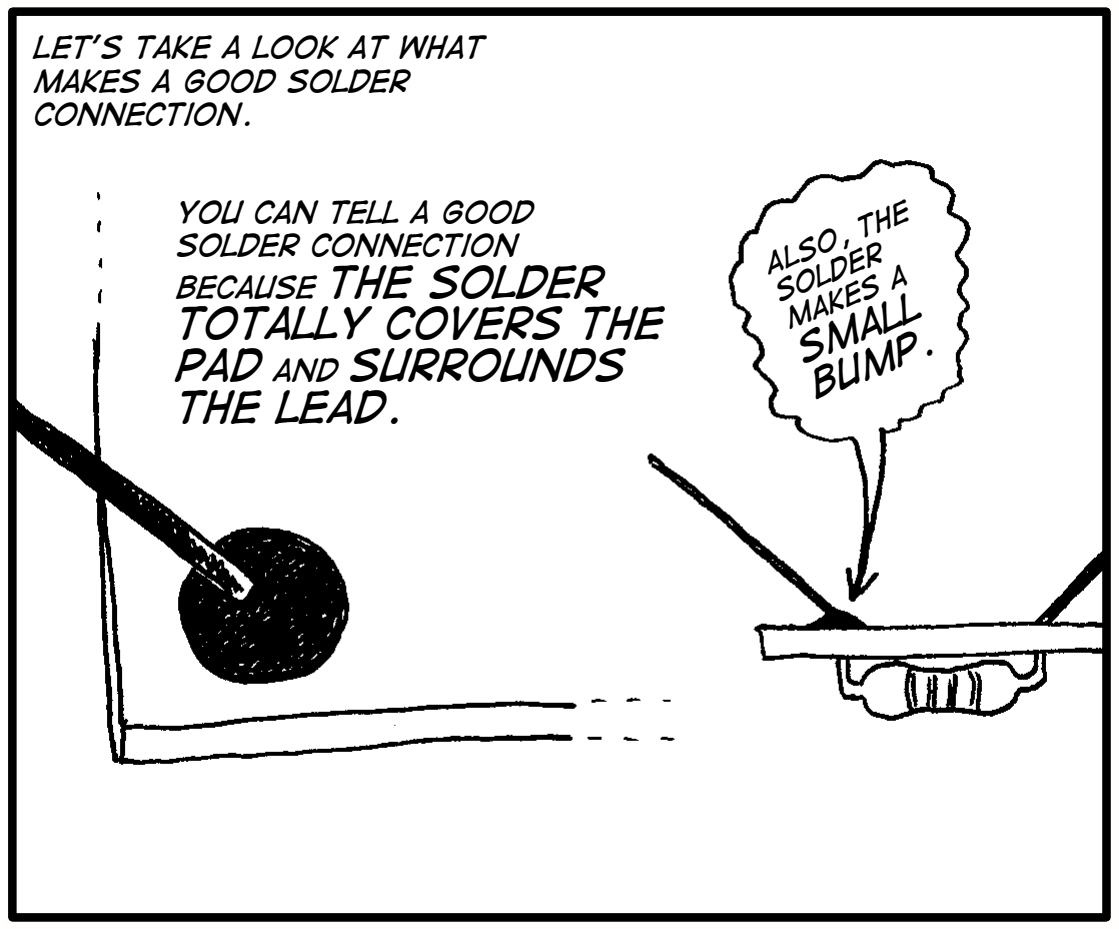
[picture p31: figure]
Let’s take a look at what makes a good solder connection.; You can tell a good solder connection because the solder totally covers the pad and surrounds the lead.; Also, the solder makes a small bump.
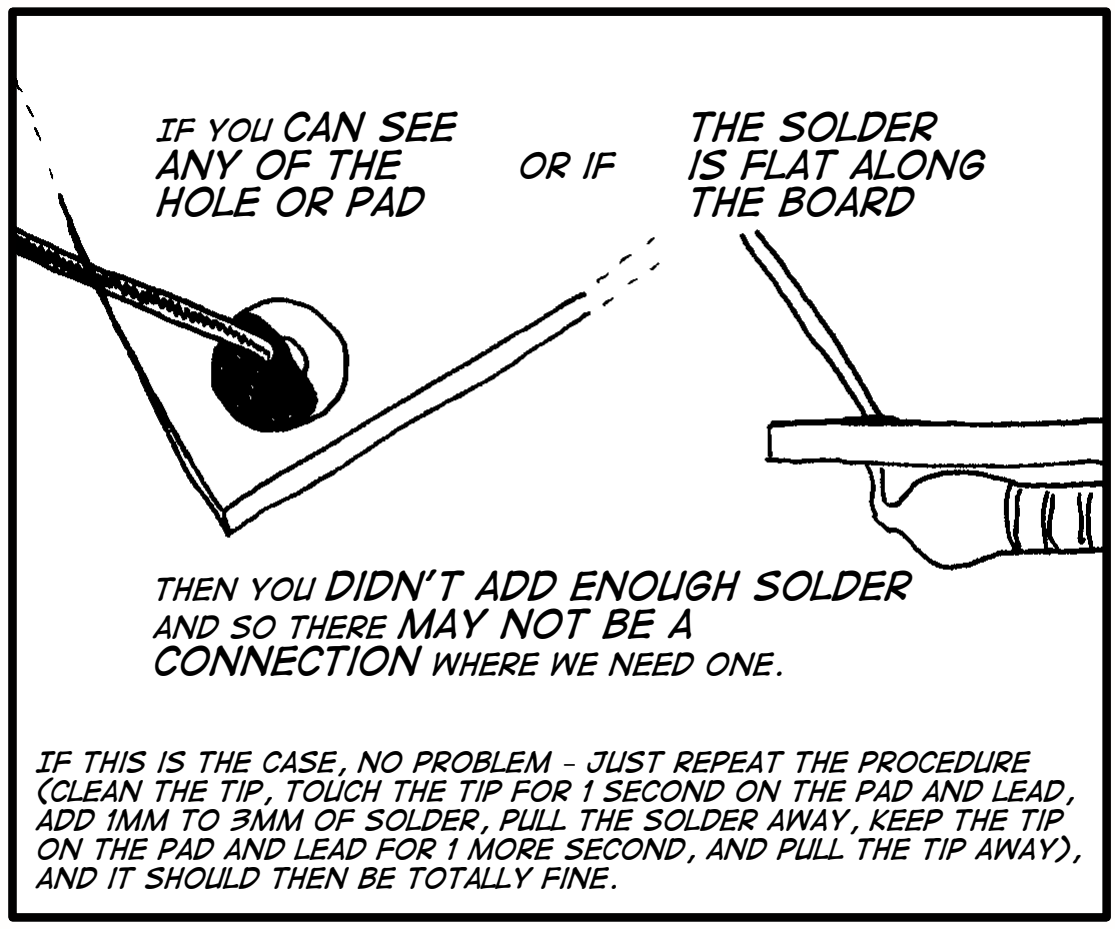
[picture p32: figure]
If you can see any of the hole or pad; then you didn’t add enough solder and so there may not be a connection where we need one.; and it should then be totally fine.; the solder is flat along the board

If this is the case, no problem – just repeat the procedure (clean the tip, touch the tip for 1 second on the pad and lead, add 1mm to 3mm of solder, pull the solder away, keep the tip on the pad and lead for 1 more second, and pull the tip away),

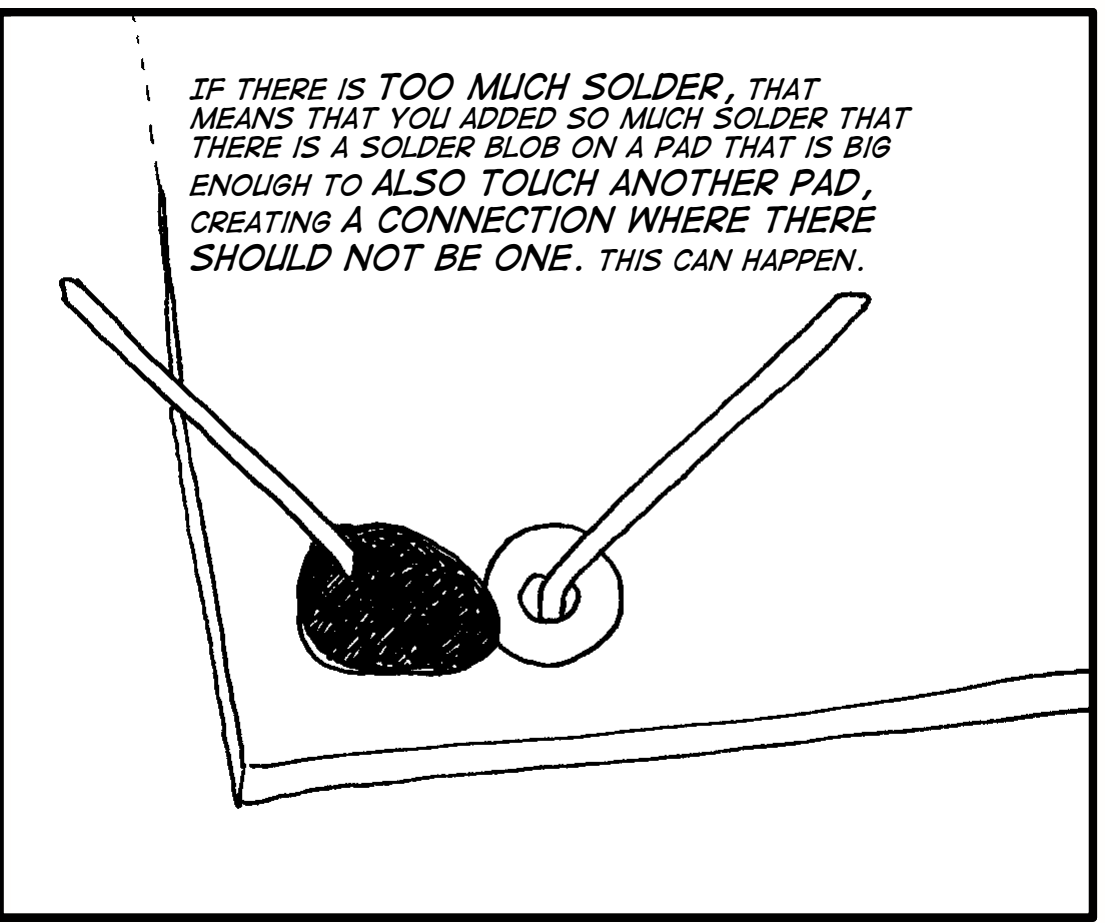
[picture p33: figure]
If there is too much solder, that; enough to also touch another pad, creating a connection where there should not be one. This can happen.

means that you added so much solder that there is a solder blob on a pad that is big

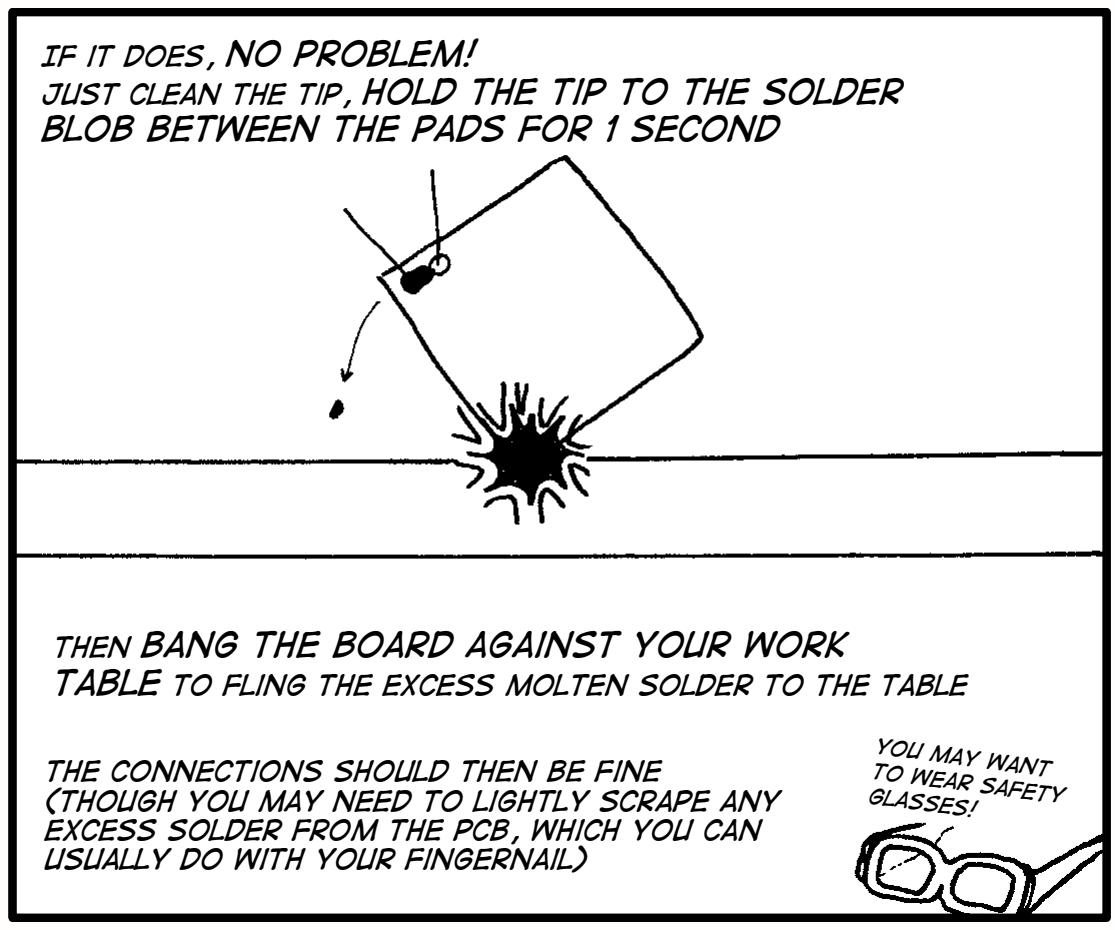
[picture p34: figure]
If it does, no problem!; blob between the pads for 1 second; then bang the board against your work; you may want to wear safety glasses!; The connections should then be fine; usually do with your fingernail)

### just clean the tip, hold the tip to the solder

table to fling the excess molten solder to the table

(though you may need to lightly scrape any
excess solder from the PCB, which you can

### In between too much and

too little solder is a
lot of leeway.
This is one reason why
soldering is easy.

Both
good! good too!

Some people like to solder parts to their pads after adding a bunch of parts to the board.

I prefer to add and solder only one part

## to the board at a time. I find this easier

since there aren’t so many leads that can get in the way of my soldering iron.

Also, if I add more than one part to the board I sometimes miss soldering a pad, since it isn’t so easy (as you might think it would be) to see which connections are soldered.

After soldering all of the leads of the part you are soldering, it is time to cut off the
excess leads.
This must be done to ensure that the excess leads do not bend over and short to another lead or pad.

if this happens, then there will be a
connection where we do not want one.

To cut the lead, we’ll use a
small wire cutter.

### One side has flat cutting

edges, and the other side has a deep groove.

### Place the flat edge down, parallel to the PCB, just at the top of the little bump of

solder.

### squeeze the handles, and the cutting edges

snap shut.

which turns the
excess lead into a

## projectile that hits you right in your eye!

## Safety tip #3 (of 3): ALWAYS hold the lead you are cutting with one hand while

you cut with your other hand.

If you always do this, you will always be safe.

you may
also
want

to wear
safety
glasses!

If the excess lead is too short to hold onto (but long enough to potentially short out to something on your PCB),
then position the wire cutter,

## hold your fingers over

the lead,

this will keep the
excess lead from
hitting anyone in
the eye (or
shorting out
somewhere on
your project)

and then squeeze.

Leads that are already very short, such as IC sockets, do not need to be cut – they have leads that are too short to bend over and make shorts.

If you make a mistake, it is totally OK.

## All mistakes are fixable (though some

are easier than others).

## And making mistakes is how we

learn to become better at everything we
do.
While soldering is easy, unsoldering

## takes lots of practice. And if you

make a mistake, you get to have some practice!

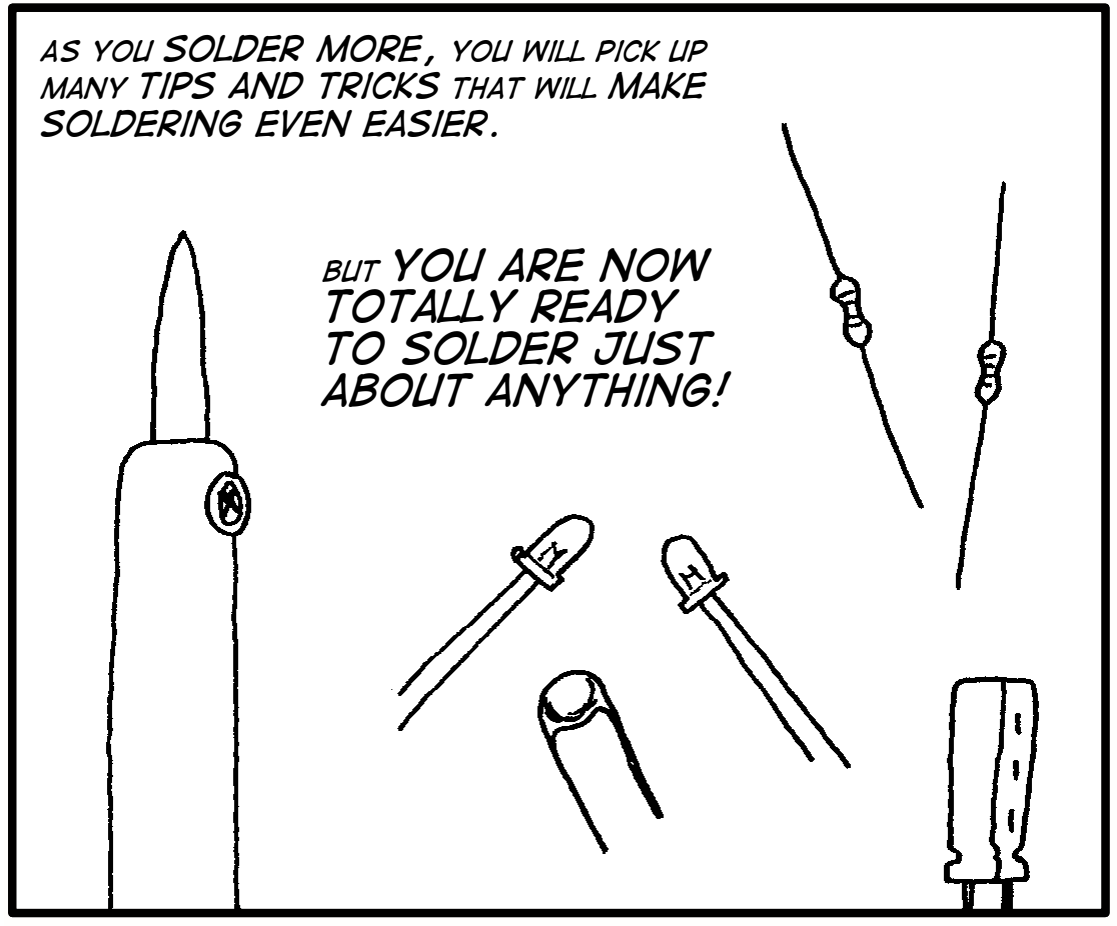
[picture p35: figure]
As you solder more, you will pick up many tips and tricks that will make soldering even easier.; But you are now totally ready to solder just about anything!

If you like soldering, and want to solder well, you’ll want to buy some good tools.

### But you do not need to spend a lot

of money to get them.

You can buy a decent soldering iron (in the shape of a long, fat pencil) for about US$15

You’ll need a

### soldering iron

stand that fits a
wet sponge,
which will cost you
about US$6

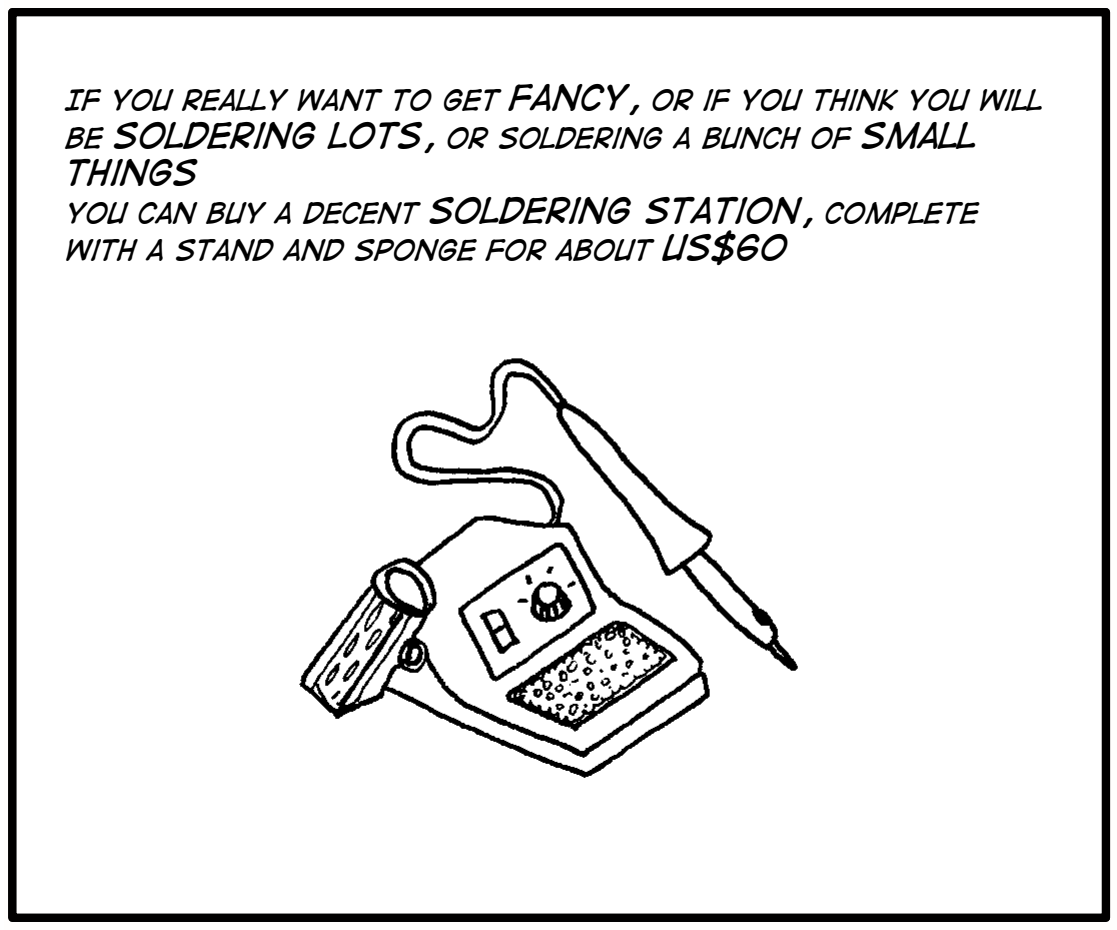
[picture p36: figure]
things; with a stand and sponge for about US$60

If you really want to get fancy, or if you think you will be soldering lots, or soldering a bunch of small

you can buy a decent soldering station, complete

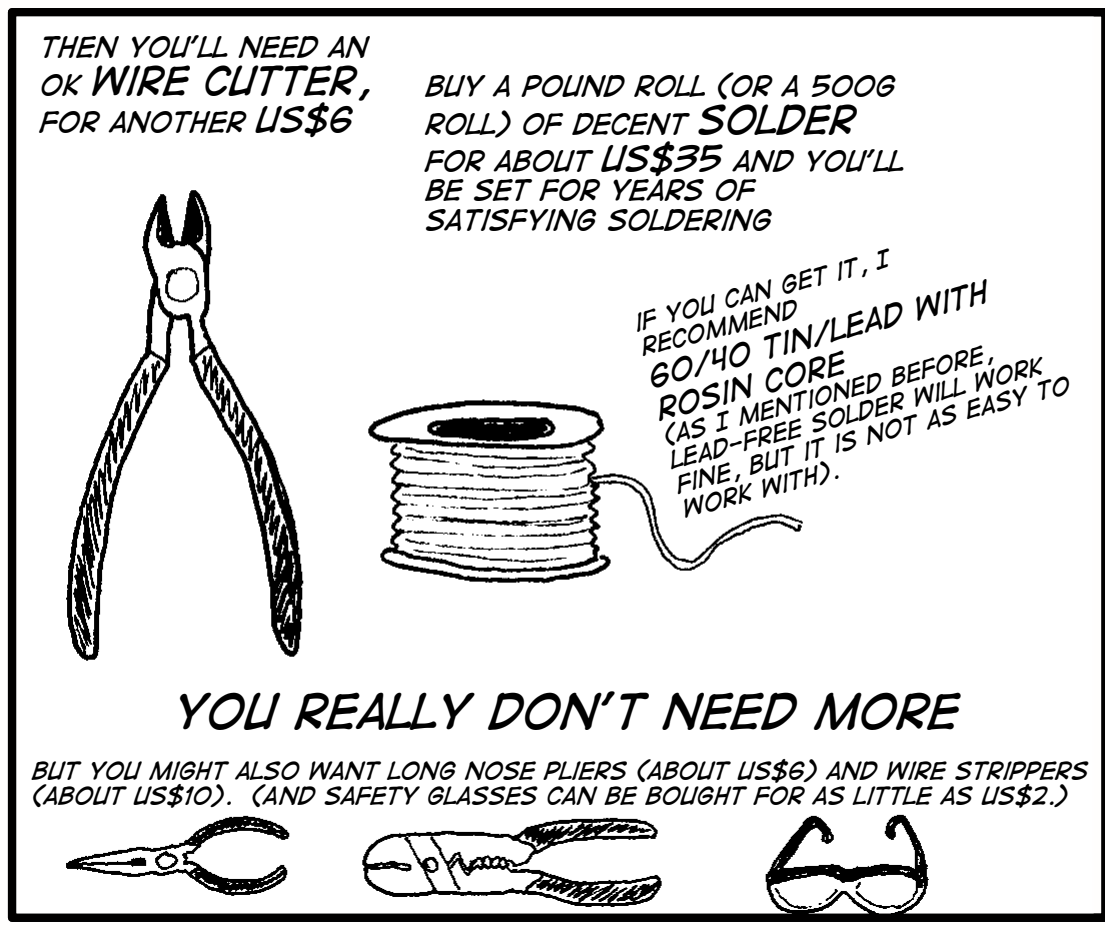
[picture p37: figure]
Then you’ll need an OK wire cutter, for another US$6; Buy a pound roll (or a 500g roll) of decent solder for about US$35 and you’ll be set for years of satisfying soldering; if you can get it, I; recommend; 60/40 tin/lead with; rosin core; (as I mentioned before, lead-free solder will work fine, but it is not as easy to; work with).; You really don’t need more

But you might also want long nose pliers (about US$6) and wire strippers (about US$10). (And safety glasses can be bought for as little as US$2.)

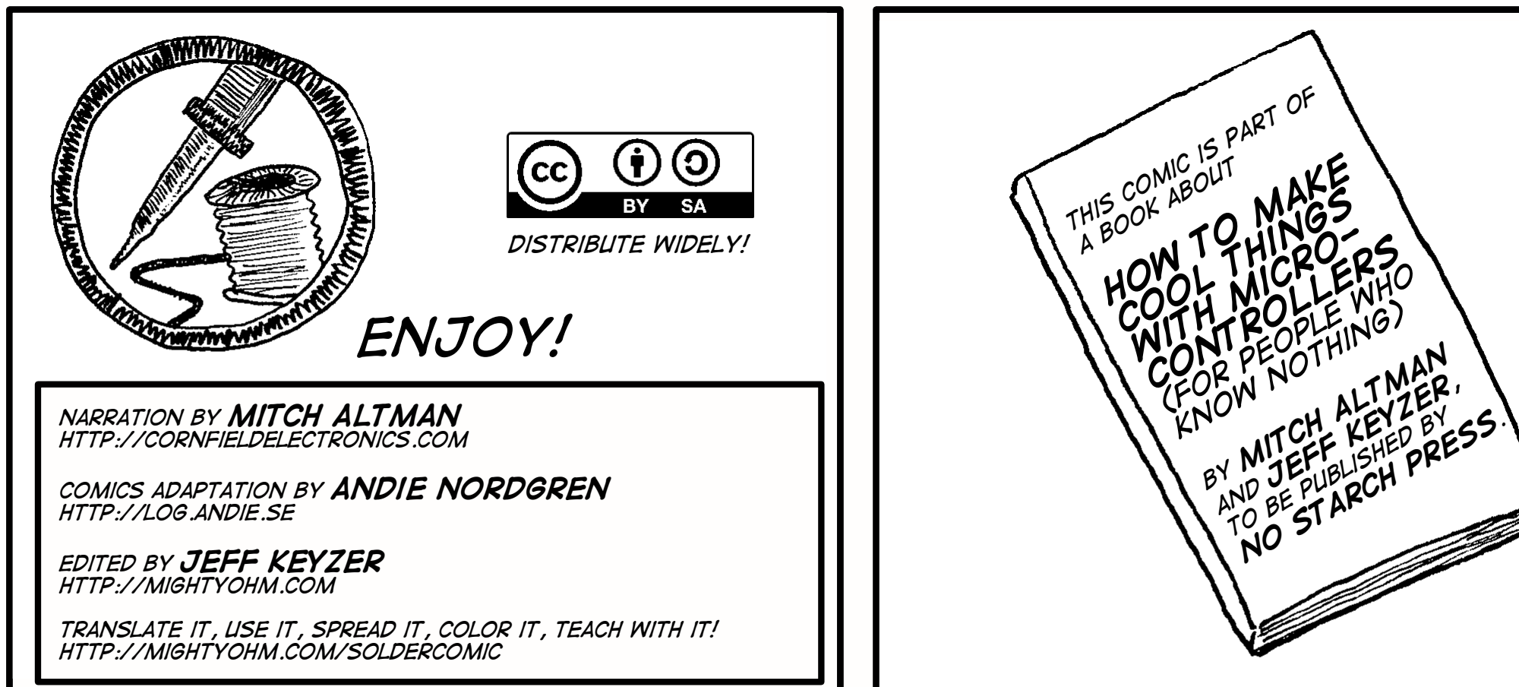
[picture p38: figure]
Narration by Mitch Altman; http://cornfieldelectronics.com; COmics adaptation by Andie Nordgren http://log.andie.se; Edited by Jeff Keyzer http://mightyohm.com; http://mightyohm.com/soldercomic; Distribute widely! Enjoy!
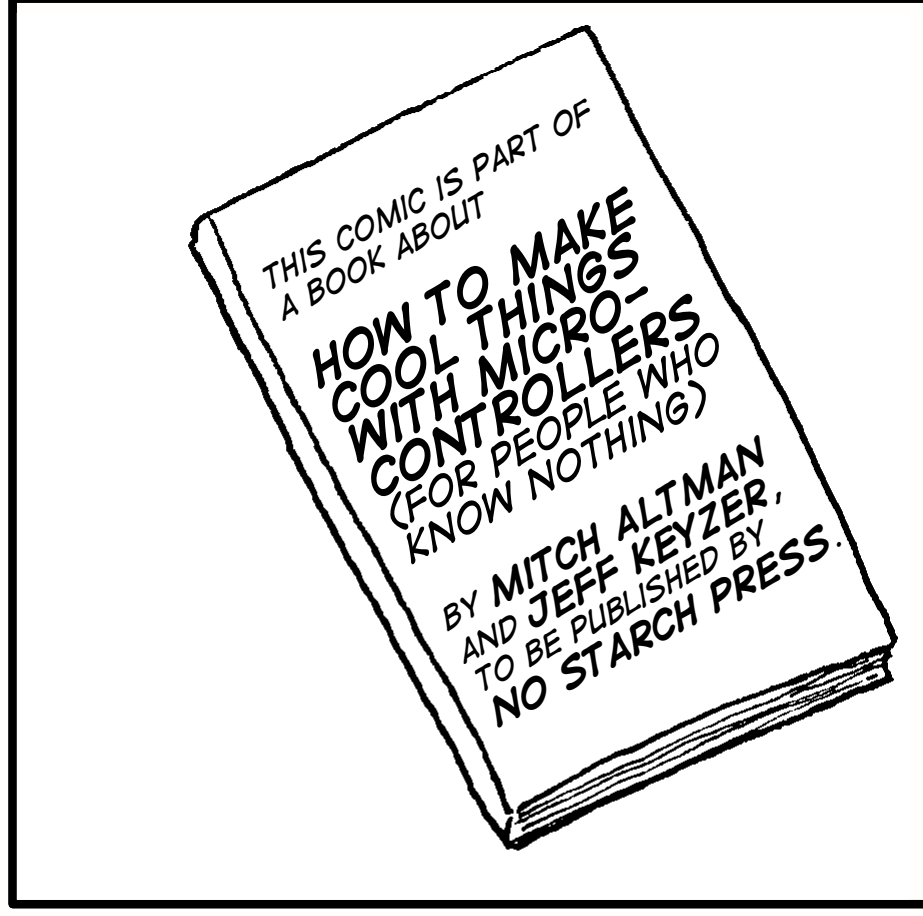
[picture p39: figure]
This comic is part of; a book about; How to Make Cool Things with Micro- controllers (For People Who Know Nothing) by Mitch Altman and Jeff Keyzer, to be published by No Starch Press

Translate it, use it, spread it, color it, teach with it!

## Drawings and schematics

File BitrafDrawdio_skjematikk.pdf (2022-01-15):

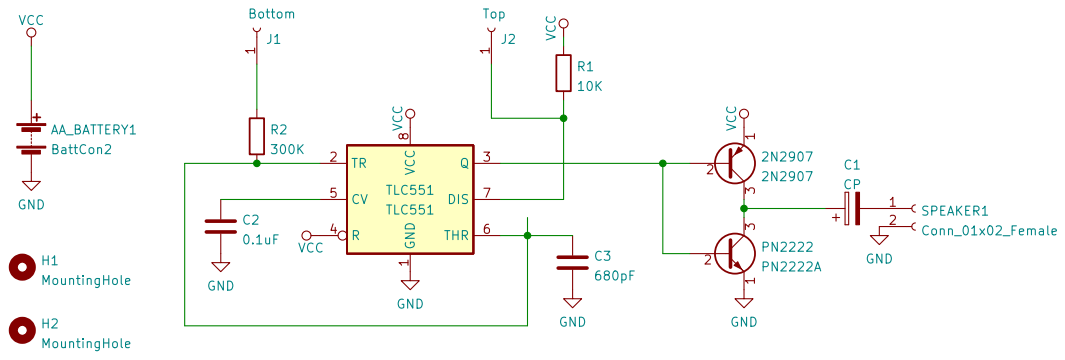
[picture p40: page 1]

group at the MIT Media Lab (CC BY-SA 3.0)
Adaption for Bitraf by Jensa
File: BitrafDrawdio.kicad_sch Sheet: / Bitraf (CC BY-SA 3.0)

Id: 1/1 Title: Drawdio for Bitraf

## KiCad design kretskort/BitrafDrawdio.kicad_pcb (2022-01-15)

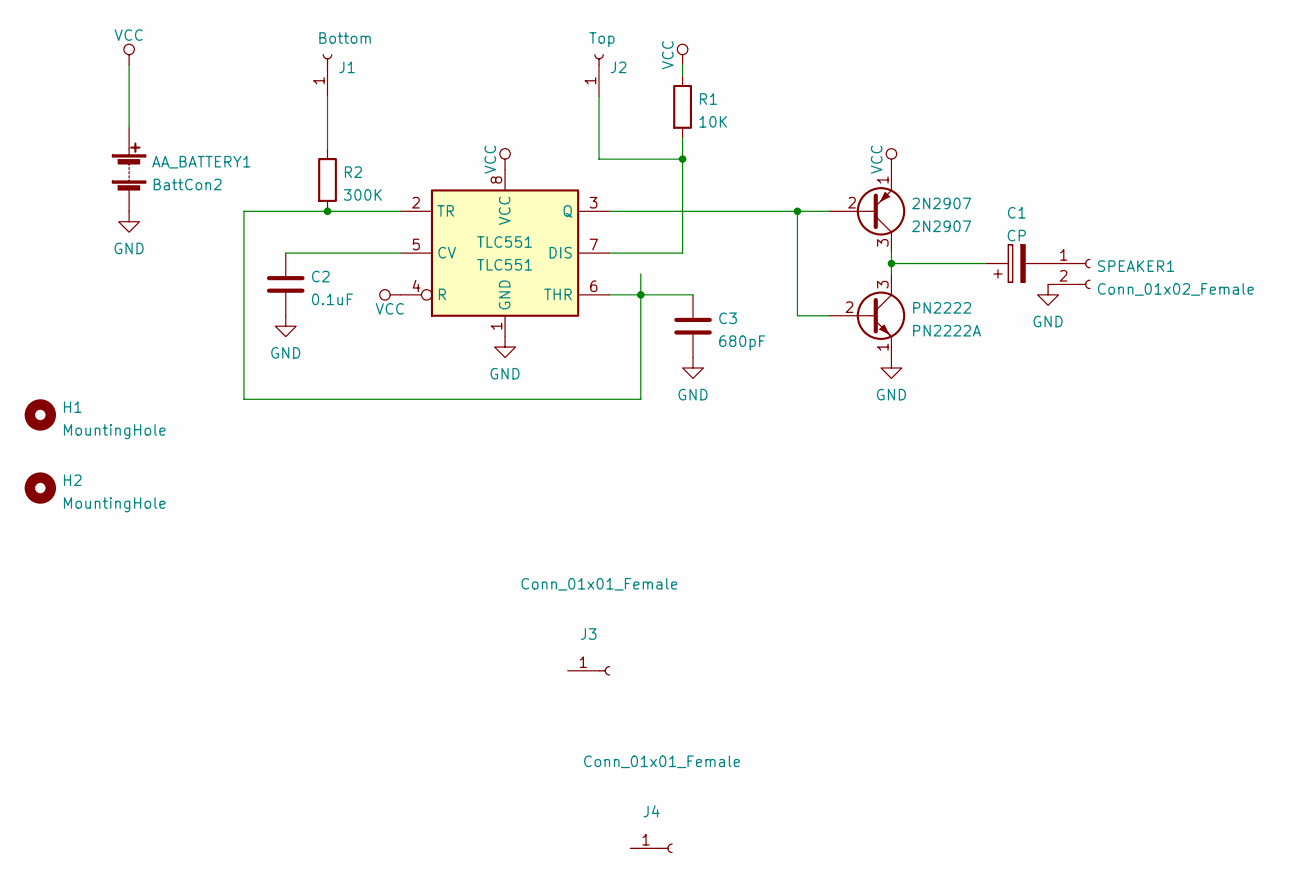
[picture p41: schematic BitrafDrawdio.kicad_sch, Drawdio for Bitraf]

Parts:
2N2907: 2N2907; TO-92_Inline_Wide; MPN PN2907ATF
AA_BATTERY1: BattCon2; DrawdioBatteryHolderAA; MPN BK92 (x2)
C1: CP; CP_Radial_D5.0mm_P2.00mm; MPN 6.3MS7100MEFCTZ5X7
C2: 0.1uF; C_Disc_D3.8mm_W2.6mm_P2.50mm; MPN K104K10X7RF5UH5
C3: 680pF; C_Disc_D3.8mm_W2.6mm_P2.50mm; MPN FA18C0G1H681JNU00
H1, H2: MountingHole; DrawdioStripsHole
J1: Bottom; DrawdioPad
J2: Top; DrawdioPad
J3: Conn_01x01_Female; Bitraf_Logo_31_x_12_mm
J4: Conn_01x01_Female; Bitraf_logo_3.0_x_7.5_mm
PN2222: PN2222A; TO-92_Inline_Wide; MPN PN2222ATF
R1: 10K; R_Axial_DIN0207_L6.3mm_D2.5mm_P5.08mm_Vertical; MPN CFR-12JB-52-10K
R2: 300K; R_Axial_DIN0207_L6.3mm_D2.5mm_P10.16mm_Horizontal; MPN RR01J300KTB
SPEAKER1: Conn_01x02_Female; DrawdioSpeaker; MPN CMS-160925-078S-67
TLC551: TLC551; DIP-8_W7.62mm_Socket_LongPads; MPN TLC551CP

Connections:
GND: AA_BATTERY1.2 (-), C2.2, C3.2, PN2222.1 (E), SPEAKER1.2, TLC551.1 (GND)
unnamed: 2N2907.2 (B), PN2222.2 (B), TLC551.3 (Q)
unnamed: 2N2907.3 (C), C1.1, PN2222.3 (C)
unnamed: C1.2, SPEAKER1.1
unnamed: C2.1, TLC551.5 (CV)
unnamed: C3.1, R2.2, TLC551.2 (TR), TLC551.6 (THR)
unnamed: J1.1, R2.1
unnamed: J2.1, R1.2, TLC551.7 (DIS)
VCC: 2N2907.1 (E), AA_BATTERY1.1 (+), R1.1, TLC551.4 (R), TLC551.8 (VCC)

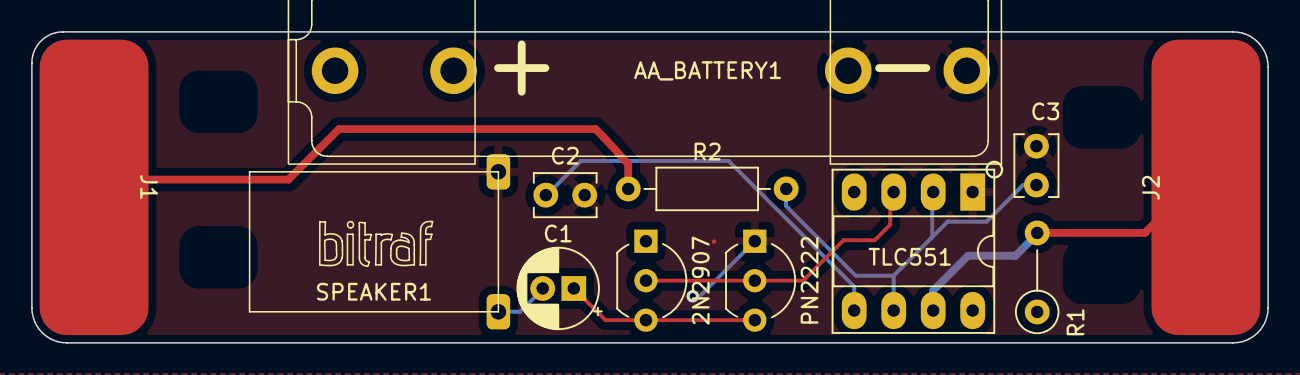
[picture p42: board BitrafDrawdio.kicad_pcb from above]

Board: 2 copper layers, 79.5 x 20.0 mm, 16 parts (1 on the bottom side), 9 nets.
